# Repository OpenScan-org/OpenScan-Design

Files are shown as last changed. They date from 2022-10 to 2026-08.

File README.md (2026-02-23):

# OpenScan - 3D Scanner Designs

Here you can find, discuss and improve the existing 3d scanner designs (and current developments). The inital version was created in SketchUp and we plan on re-creating the OpenScanners in proper CAD software. If you are able to "translate" the designs into some other, more accessible format, you can also share it here.

The documentation is separated in parts, and can be found in the /docs/ folder:

[**Printing Guide**](/docs/OpenScanV2-Part-Printing.md)

[**Assembly Guide for Mini and Midi**](/docs/OpenScanV2-Assembly.md)

[**Electronics Guide for green and black shield**](/docs/OpenScanV2-Electronics.md)

[**Black Shield Manual**](docs/Black%20Shield%20V2.pdf)

# OpenScan Mini V1
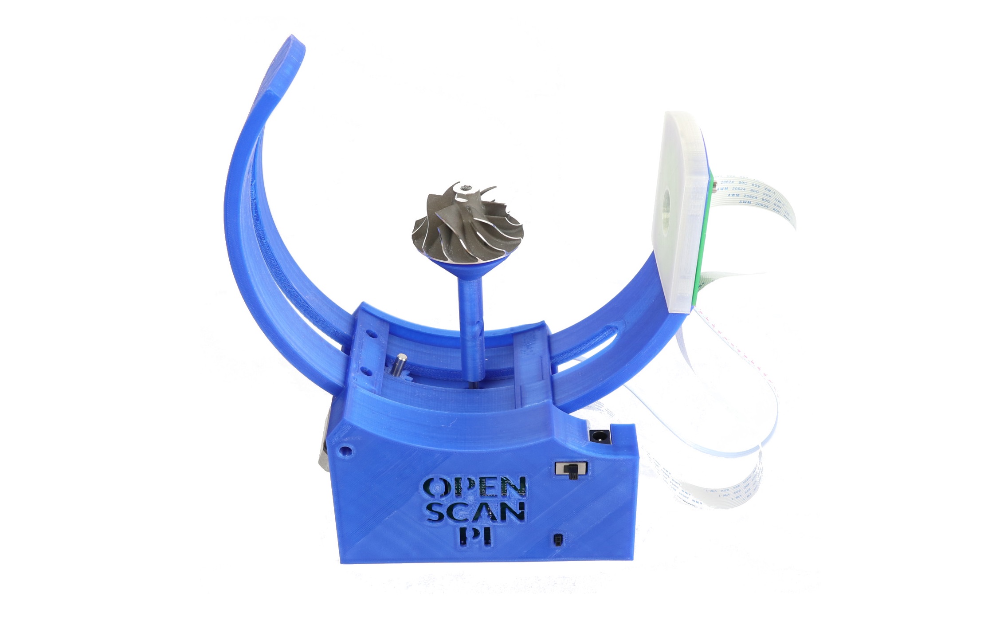
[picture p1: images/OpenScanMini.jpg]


The OpenScan Mini is the smallest version of the scanner. It has an approx. scan volume of a sphere with a diameter of 8-9cm, perfect for small and detailed parts. It features built-in LED lighting and polarizers to uniformly illuminate parts and to suppress reflections.
Version 1 is the current release with configured OpenScan software, which is described in the documentation. All hardware kits sold with the current kits are for the Mini V1 and the Classic

# OpenScan Mini V2.X
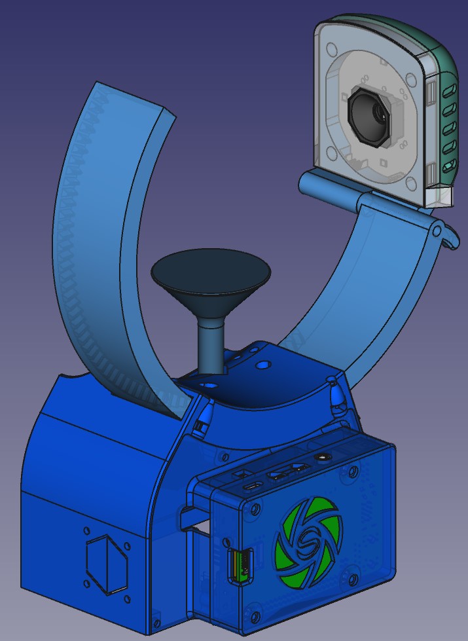
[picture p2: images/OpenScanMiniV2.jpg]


Version 2 is also available. We have seen various user mods to add functionality to the OpenScan platform. We aim to incorporate as many user mods as possible in the new design and to make adding mods more user-friendly. The idea is to increase printability, stability, and stiffness, include mounting options for user mods, and allow modular use of various cameras and lighting.
The design of version 2 is aimed at the OpenScan Shield Version 2 ("black shield", not released yet, for info, visit the Discord channel) but can also be used for the current "green shield". The BOM is slightly different from V1, various screws can be recycled, and the remaining is not exotic.

## BOM V2.0

[**BOM V2.0**](/docs/BOM-V2.0.md)

## BOM V2.1 + V2.2

[**BOM V2.1**](/docs/BOM-V2.1.md)

## BOM V2.3

[**BOM V2.3**](/docs/BOM-V2.3.md)

## BOM V2.4

[**BOM V2.4**](/docs/BOM-V2.4.md)

# OpenScan Midi V2.X
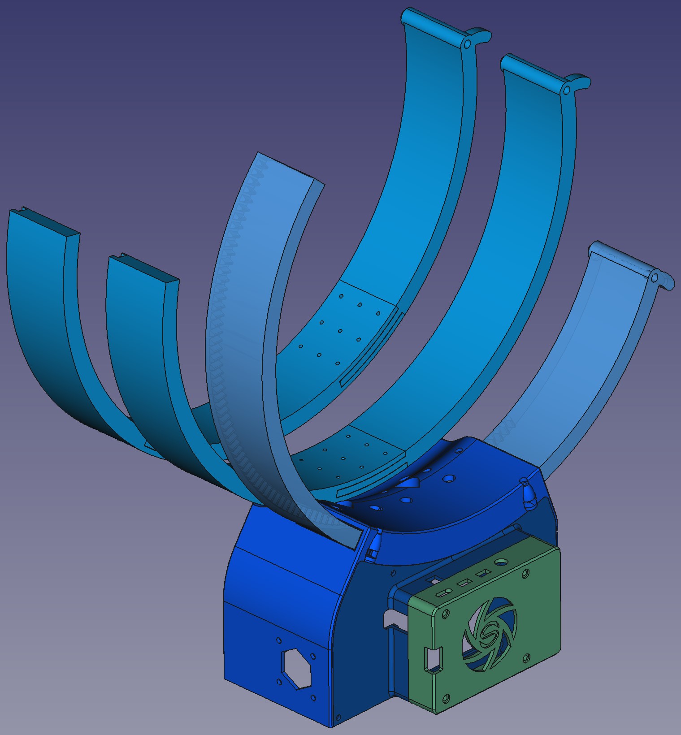
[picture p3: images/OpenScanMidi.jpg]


A scaled-up version of the Mini allows for larger objects to be scanned. The scanning volume is approx. a sphere with a 16cm diameter. This is the largest size before the flat cable for the camera slowly loses signal integrity, resulting in occasional camera hiccups. The Midi uses the same BOM as the Mini V2.
The rotor has a diameter of 30cm and is too large for many build plates. Thus, a segmented version is also provided. The segments slide into each other and are fixated afterwards with filament pieces through the 9 holes (and a little CA glue if necessary) or via M2/M2.5 grub screws of approx length 10mm. The transition of the segments must not have imperfections which could otherwise get caught in the cog wheel or brearing flanges. The large rotor benefits from the non-essential bearing upgrades to reduce wobble.

## BOM V2.0

[**BOM V2.0**](/docs/BOM-V2.0.md)

## BOM V2.1 and V2.2

[**BOM V2.1**](/docs/BOM-V2.1.md)

## BOM V2.3

[**BOM V2.3**](/docs/BOM-V2.3.md)

## BOM V2.4

[**BOM V2.4**](/docs/BOM-V2.4.md)

# OpenScan Classic
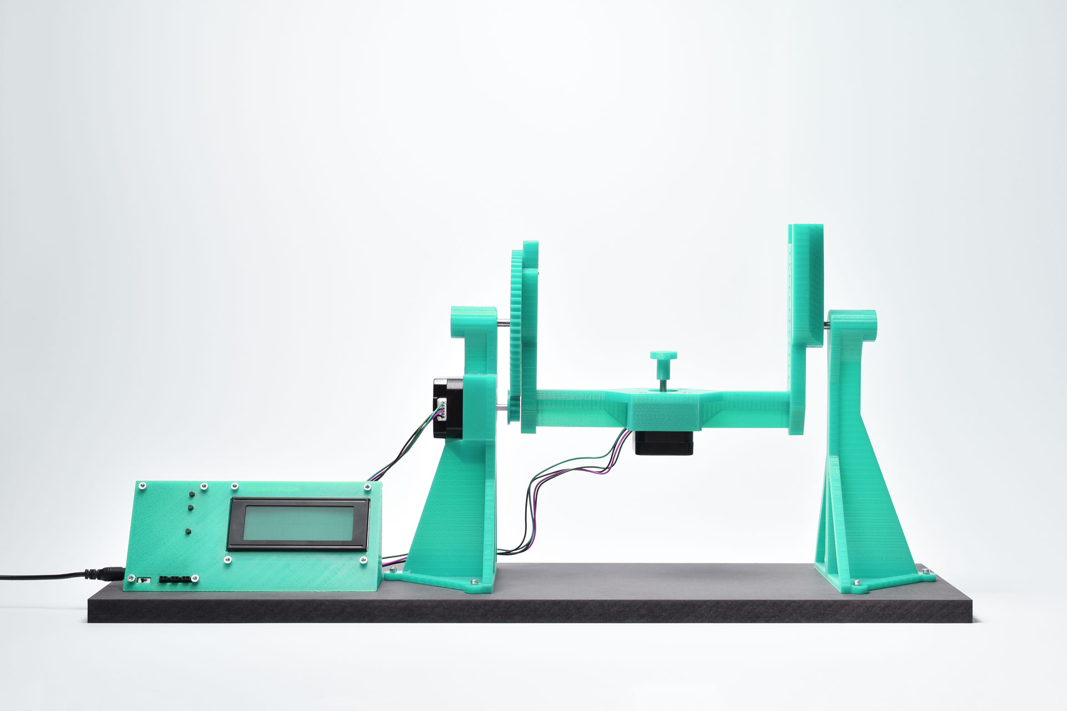
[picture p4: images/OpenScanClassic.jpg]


The OpenScan Classic is for larger objects and potential usage of external cameras. The Classic is scaled to fit much larger items. It functions the same as the Mini, except the camera is in a fixed position and the object is rotated and tilted. 

# User Mods for OpenScan Scanners
You can actively help design the OpenScan Scanners and provide user mods for others. We have seen many design tweaks and changes from users on Thingiverse and other platforms. Unfortunately, the user mods on other platforms are slowly getting lost or outdated. Here, we want to provide a platform for you to exchange your user mods and the option to curate mods so they are not getting lost in time and space. 

## Design "rules"
We recommend sticking to common design rules of 3D printing. When designing a part, printability should always be in the back of your mind, i.e., try to avoid angles larger than 45° and, if not preventable, try to include support structures already in the model so that other users will have an easier time printing. The designed part should also be rotated such that it is ready to print. For hardware parts, try to stick for parts that are commonly used in 3D printing, e.g., metric screws like M3x8mm, heat inserts like in Voron and other printers, or bearings like from skateboards or Bontech idlers.

## How to contribute Designs and provide Mods
If you are familiar with Git Hub, you already know how to contribute to projects. In case you are new to GitHub, the way would be to create an account, create your fork of the project (fork = personal copy you can edit), and then you can add (and/or change) user mods (user mods have a dedicated folder). Finally, you can create a pull request of your changes and user mods to the official OpenScan Project. After checking and approving your report and pull request, your user mods will be listed on the official GitHub page. If you are unsure about the whole process or want to share a single STL with the community, you can also ask for help on our Discord channel. The curators of the GitHub project can help you there.

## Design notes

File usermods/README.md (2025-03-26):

# Collection of your user mods.

This side is meant for adding small descriptions of various user mods. Every user mod will be placed into a separate folder.

## Small Overview of User Mods

Update the following table with the information about your mod:
- Your name
- A link to your sub-folder
- A short description of your mod
- The component the mod is designed for. Use `:heavy_check_mark:` for :heavy_check_mark:,`:x:` for :x:

like so:
`
| Creator | [Mod title](link) | Description | Mini V1 | Mini V2 | Midi | Classic | STEP | F360 | FreeCAD |`

| Creator | Mod/Folder Name | Short Description | Mini V1 | Mini V2 | Midi | Classic | STEP | F360 | FreeCAD |
| :---: | :---: | :---: | :---: | :---: | :---: | :---: | :---: | :---: | :---: |
| Alan Devine | Turntables for D-shaped Shaft | Mod name is self-explanatory. D-shaped hole provides proper form-fit of the shaft and the turntable  | :heavy_check_mark: | :heavy_check_mark: | :heavy_check_mark: |  :x: | :heavy_check_mark: | :heavy_check_mark: | :x: |
| ep1cman | Platform Holder | Base Plate with 4 slots for turntable storage | :x: | :heavy_check_mark: | :x: | :x: | :heavy_check_mark: | :x: | :x: |
| advisoray | ScanDome | Add a removable dome to block out any distracting noise from scanner background | :heavy_check_mark: | :x: | :x: | :x: | :heavy_check_mark: | :x: | :x: |
| elvum | Enhanced Diffuser (Classic) | A diffuser for the Openscan Classic with a camera shade to block scattered light, and polariser holders | :x: | :x: | :x: | :heavy_check_mark: | :heavy_check_mark: | :heavy_check_mark: | :x: |

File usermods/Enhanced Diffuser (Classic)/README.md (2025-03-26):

# Enhanced Diffuser (Classic)

This is an enhanced version of the diffuser for the OpenScan Classic.  The design has three main improvements:
* The rectangular cut-out is sized correctly for the Arducam IMX519 16MP camera that at the time of writing was the default choice for the OpenScan Classic.
* A camera shade is provided to prevent light reflecting from the diffuser entering the camera from oblique angles, resulting in wash-out.
* Holders are provided for the polarising filters to secure them in place.

In addition, templates are provided to help cut the polarising filter material to the right sizes.

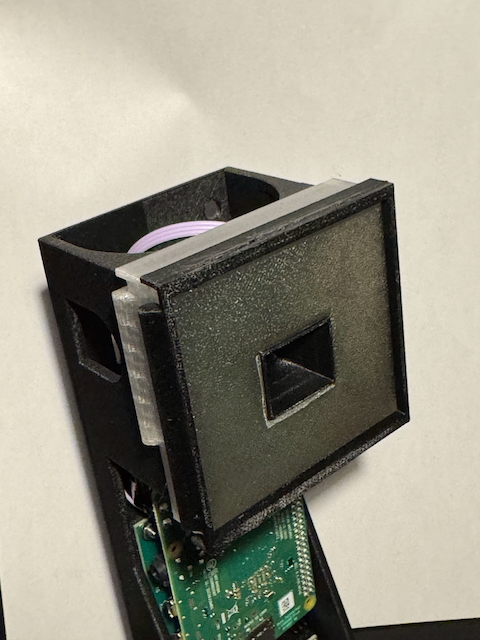
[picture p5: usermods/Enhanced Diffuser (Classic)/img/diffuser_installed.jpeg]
|  |
|:--:|
| The whole assembly, shown installed. |

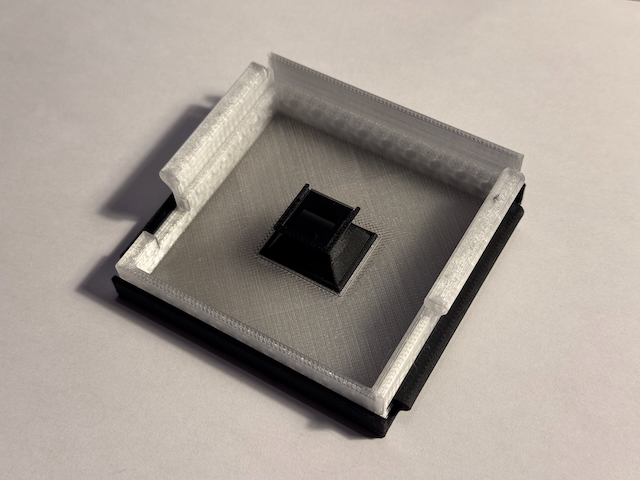
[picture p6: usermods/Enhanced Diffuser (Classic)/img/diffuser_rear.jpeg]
|  |
|:--:|
| The rear of the assembly, showing the camera shade with one of the two polarising sheets installed at its rear. |

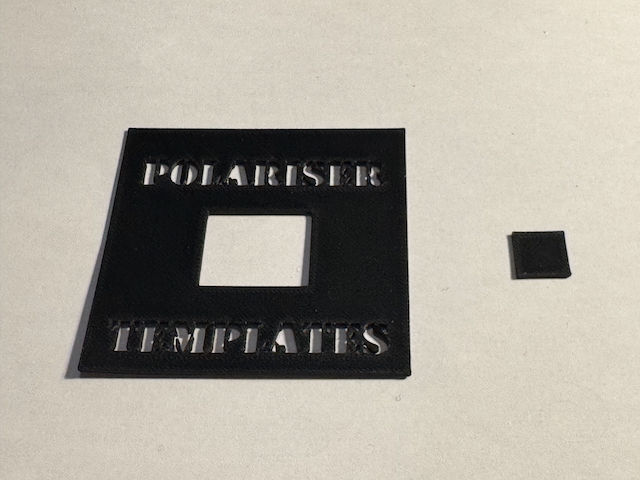
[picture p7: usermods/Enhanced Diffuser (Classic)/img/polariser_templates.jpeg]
|  |
|:--:|
| The two templates for cutting down polarising film to the correct dimensions. |

## Printing

The diffuser should be printed in an uncoloured translucent filament such as PETG.  The camera shade should be printed in a matte black material - it was tested with Bambu PETG-CF.  Other parts can be printed in whatever material takes your fancy, although they have only been tested in the same black PETG-CF that was used for the camera shade.  A textured build plate produces a nice rough texture on the face of the diffuser and is fine for all other parts too.  No support is required.

The design has been tested using Bambu Studio to slice before printing on a Bambu X1C with an 0.4mm nozzle and the Textured PEI build plate.  The 3MF file used to print it is included in this folder, along with a STEP file, STLs for each part plus the assembly as a whole, and the Fusion 360 source.

## Assembly

Unlike the original diffuser, which could be slid onto the camera enclosure from the top, this version clips onto the front of the enclosure, but uses the same rails.  No modifications to the enclosure are required.

To assemble the diffuser, insert the camera shade through the rectangular hole in the front and clip it into place - if you intend to use polarisers, make sure that the slot at the back of the camera shade is pointing upwards.  To install the polarisers, first cut out the correct profiles from a sheet of polarising plastic - printable templates are provided to help with this.  Make sure you cut out the rectangular hole in the larger sheet so that it fits around the outside of the camera shade, and make sure that the two filters are cut from one sheet of polarising material, without any rotation of the material between them.

Place the large sheet of polariser on the _front_ of the diffuser and use the large retaining clip to secure it in place.  Then place the small sheet into the slot at the back of the camera shade.

The small polariser is square, allowing it to be inserted into its holder in more than one orientation.  Make sure that it is oriented correctly by clipping the diffuser onto the OpenScan enclosure and placing a reflective plastic object in front of the camera - the lid of an aerosol can, maybe.  Launch the OpenScan web app on your computer (by browsing to http://openscan or http://openscan.local) and click "scan" to preview the live images from the camera.  Rotate the small polariser by one quarter turn and see which of the two orientations minimises the reflections as seen in the live preview.  When you have identified the right orientation, you can secure the small polariser with a dab of glue, if you wish.

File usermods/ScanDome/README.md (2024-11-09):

# ScanDome v1.2

Block out a noisy background for cleaner scans.  This is specifically built for the OpenScan Mini (Classic) v1.

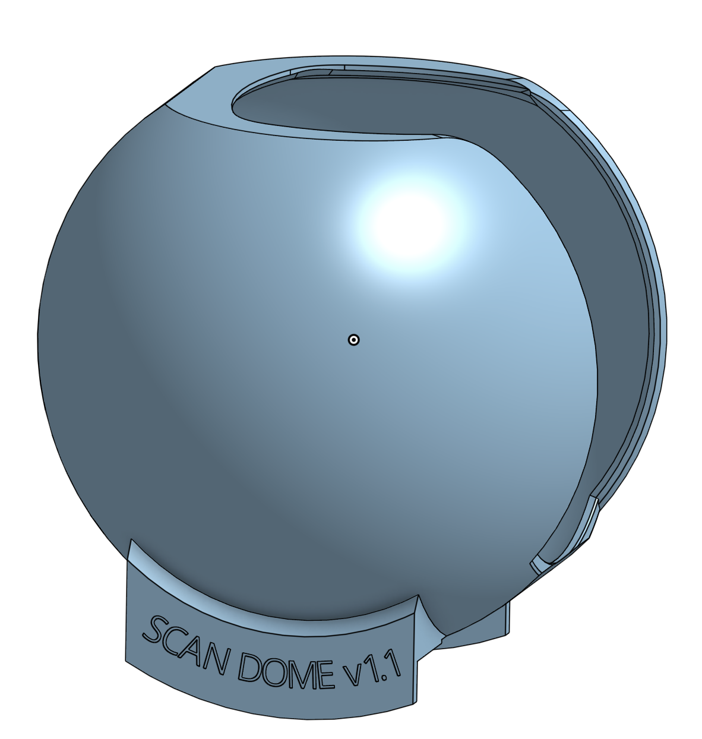
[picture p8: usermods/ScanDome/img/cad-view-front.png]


## Design

The ScanDome sits freely on the base of the OSMini (Classic) v1. The rotor will freely rotate around the ScanDome. The camera and ring light will fit comfortably through the opening.  No modification to the OSMini (Classic) v1 is necessary and the ScanDome may be removed and replaced freely.



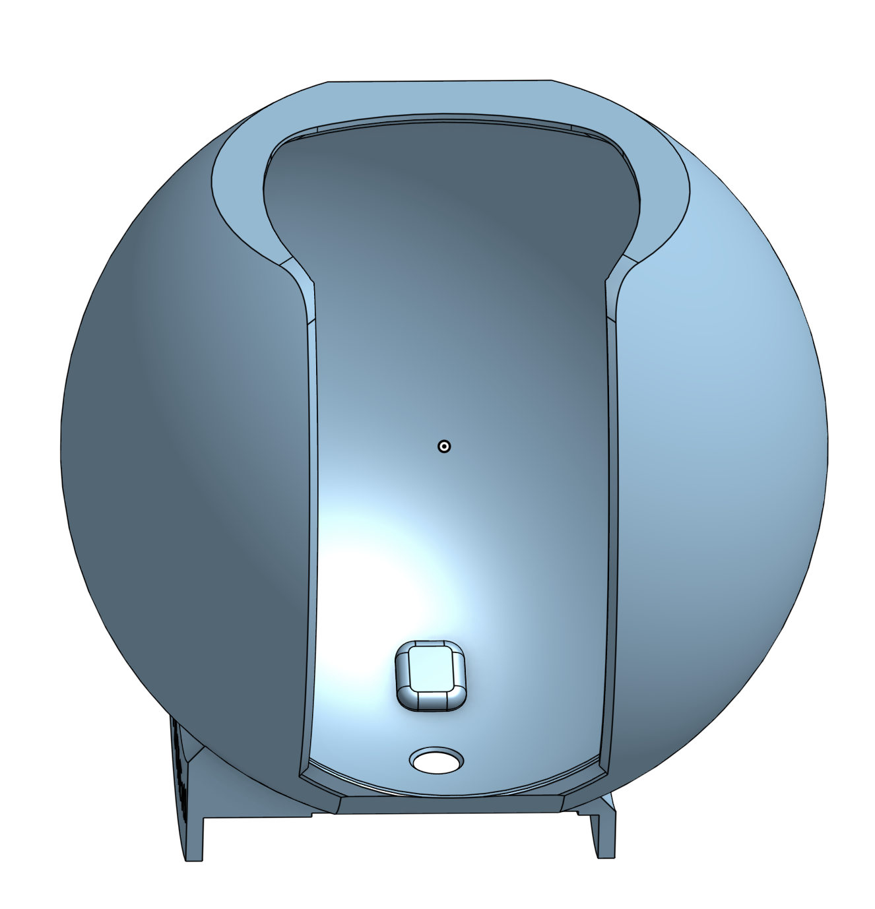
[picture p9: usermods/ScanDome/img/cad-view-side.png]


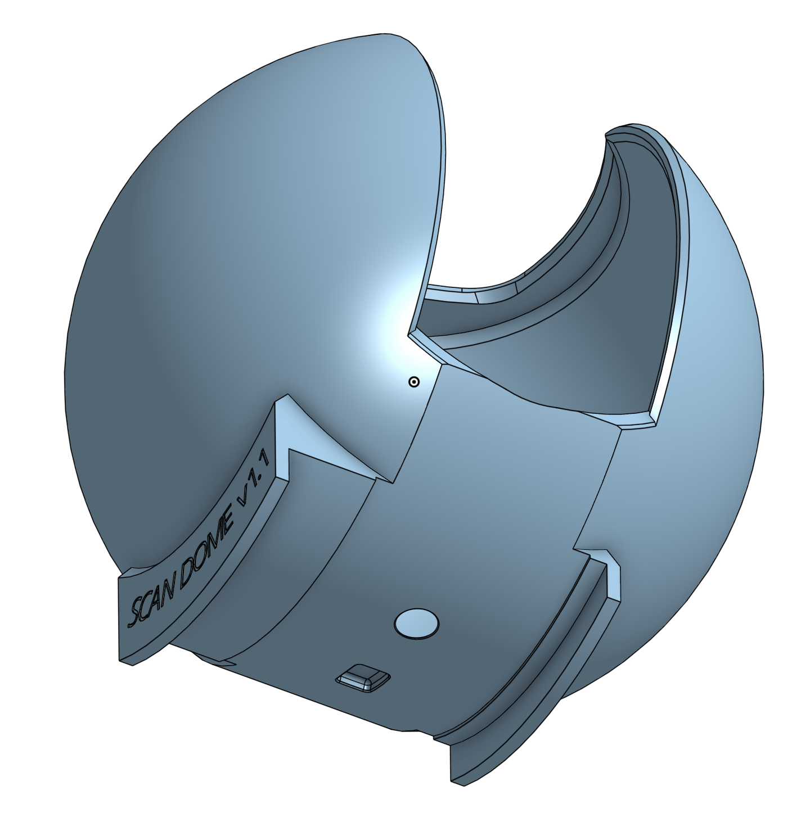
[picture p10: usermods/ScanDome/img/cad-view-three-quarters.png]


## Printing

Print on the flat surface on the top of the ScanDome (i.e., upside down from the intended deployment position).  The v1.2 version is positioned correctly so you can just import to your slicer directly and it will be correctly oriented.

Support is not strictly necessary but will improve the print quality around the hole for the turntable servo.  Low infill and low number of walls recommended -- this is not a structural part.

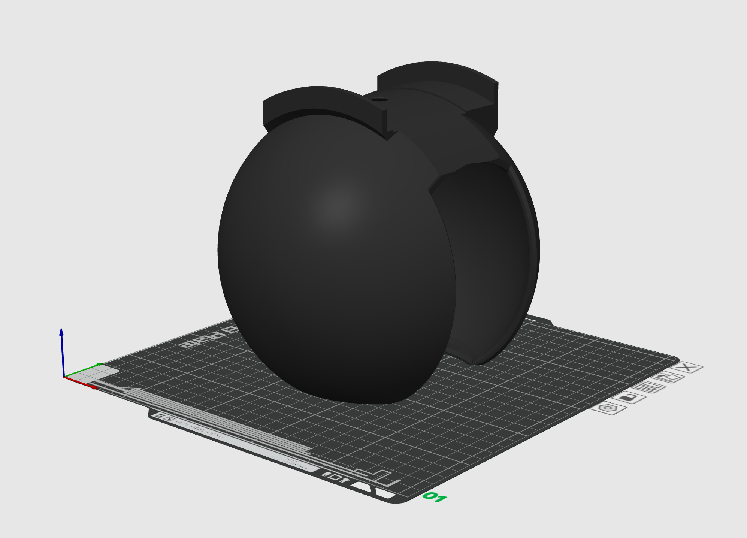
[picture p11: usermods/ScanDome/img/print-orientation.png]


## Real Example

v1.1 Printed in Inland White PLA+.

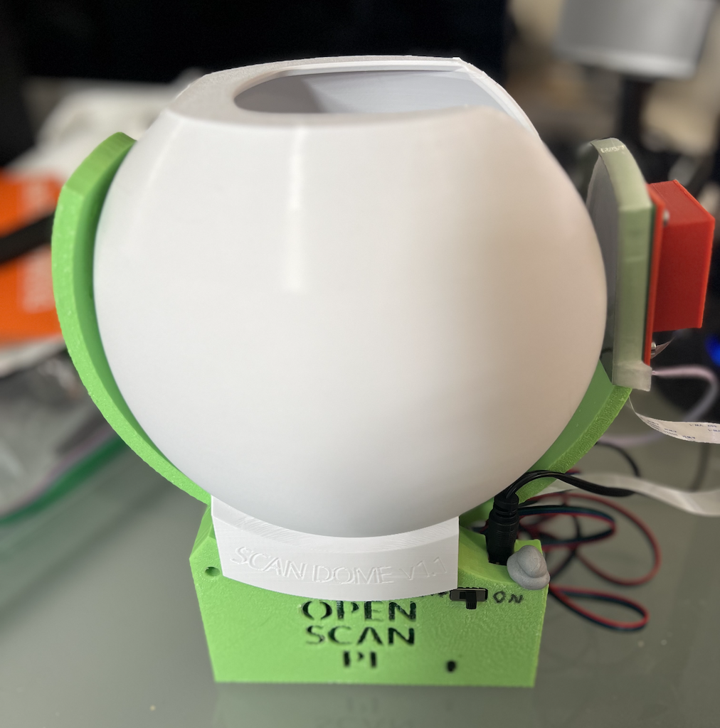
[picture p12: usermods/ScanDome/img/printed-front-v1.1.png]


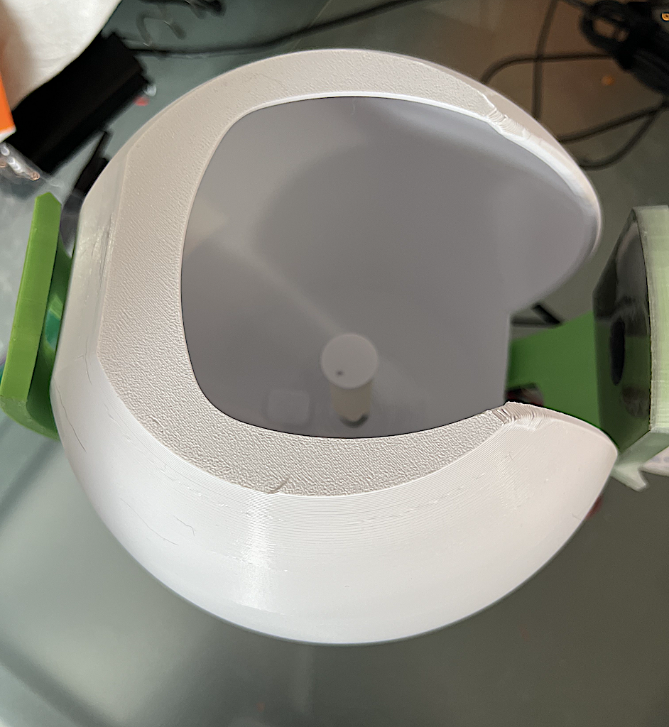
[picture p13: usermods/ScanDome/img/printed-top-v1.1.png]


v1.2 Printed in Polyterra Polylite Black ABS (No Supports).

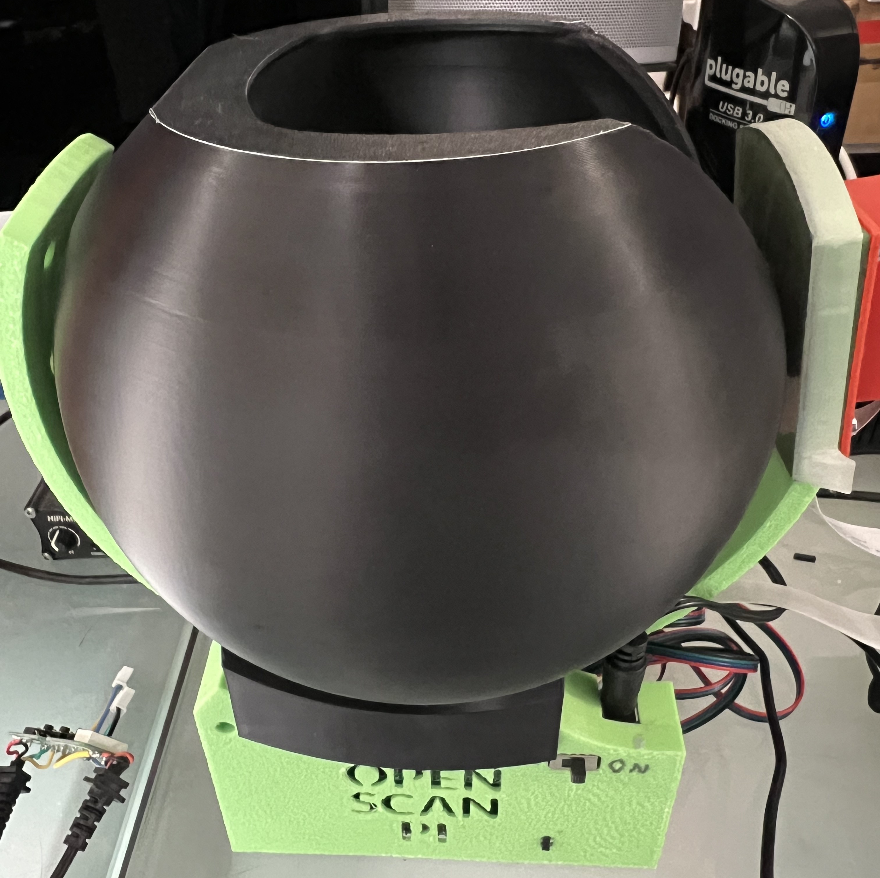
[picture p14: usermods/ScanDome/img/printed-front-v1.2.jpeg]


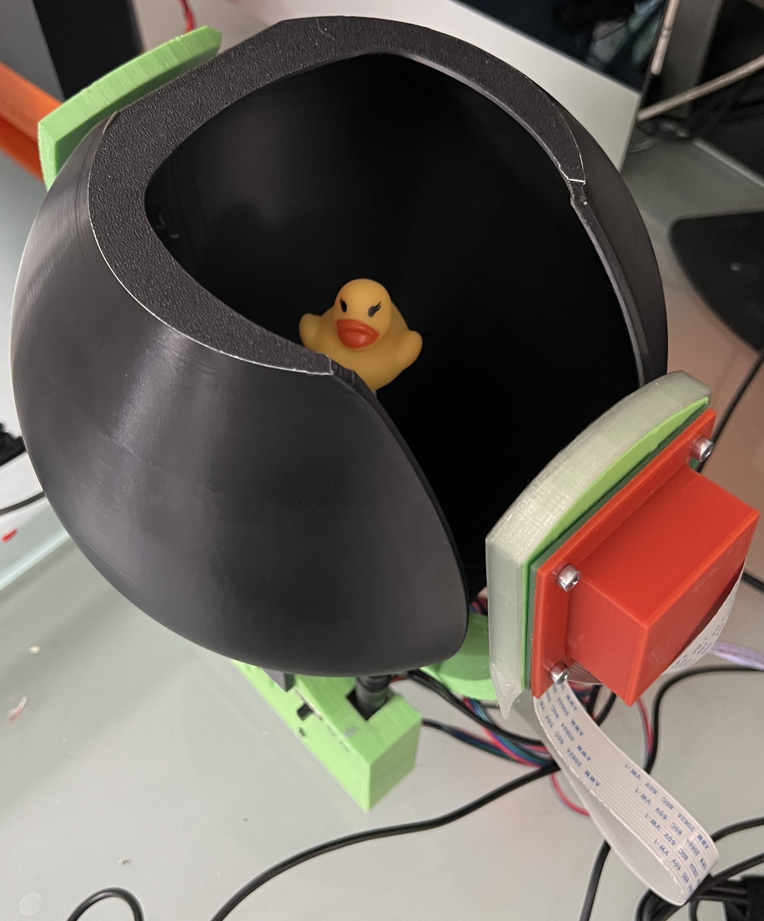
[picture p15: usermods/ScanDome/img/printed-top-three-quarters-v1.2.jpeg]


## Extending

This was designed in OnShape.  Feel free to make a copy yourself and change it to suit your needs.

v1.1: [https://cad.onshape.com/documents/bbc5671350f2efceec423882/w/e5e7f9a0af473f2fc05592b5/e/c94886a7ce4cdc3cb071335e](https://cad.onshape.com/documents/bbc5671350f2efceec423882/w/e5e7f9a0af473f2fc05592b5/e/c94886a7ce4cdc3cb071335e)

v1.2: [https://cad.onshape.com/documents/bbc5671350f2efceec423882/w/e5e7f9a0af473f2fc05592b5/e/39974ac23446baa6102c6c2a](hhttps://cad.onshape.com/documents/bbc5671350f2efceec423882/w/e5e7f9a0af473f2fc05592b5/e/39974ac23446baa6102c6c2a)

## Change Log

### Version 1.2
* Removed engraved text and version number
* reoriented print direction
* opened up hole for second servo shaft

### Version 1.1
* Initial public release

## Author

Ben Gemperline (@advisoray).  Donated to the OpenScan project.

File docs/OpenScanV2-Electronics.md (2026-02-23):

# Intro: OpenScan Electronics Start-up Guide
The OpenScan PCBs are meant for tinkerers and people with a little electronics knowledge. They are not a 100% fail-safe product (no electronics really are). In case you are not confident in dealing with electronics, here is a small, step-by-step manual on how to get the PCBs tested and running, or how to figure out where an issue is, so that you or others can help you out. This guide is written for the "black shield", but will also work for the V1, "green shield", albeit all images and references are made for the black shield. 

## Chapter 0: "Trust is good, control is better" or "Trust, but verify"
Before fully assembling your OpenScan device, you should do a pre-flight electronics check as far as you have the equipment, i.e. a multimeter, a non-conducting underground, and perhaps a Philips/Pozidrive screwdriver. You don't need any printed parts for that. *In fact, the whole process is easiest when not fully assembled, the PCBs naked in front of you on an ESD mat.* We now go through all components that can cause issues, when not handled properly.

## Chapter 1: Disconnect all components; Checking the DCDC
Remove all components, RPi, motor drivers, and cables, from the shield. You are left with the bare shield that contains only the DCDC and a few passive components. Connect a 12V power cable and switch on the shield or USB-C PD to the black shield. Nothing should happen since nothing is connected, but the DCDC will be active! With a multimeter check if you can verify GND, 12V, and 5V or more precisely 5.2V with the black shield. The black shield has status LEDs that indicate the voltage levels, so no multimeter is needed. The easiest access points are the three huge solder pads of the DCDC. If that is the case, your DCDC works, no need to check any currents since there is nothing connected that requires power, except for tiny LEDs. 
*Green Shield only:* If your 5V is off, you can adjust the voltage with the potentiometer with a screwdriver (annoying to adjust, OR flip over the DCDC, cut the potentiometer trace, and bridge the "5V" solder jumper. *I highly recommend the solder jumper bridge. It is the most reliable 5V source.*
After confirming that the DCDC works, you can continue and install jumper

Scanner

## Chapter 2: Checking the motor drivers
Switch off the shield again. Now, plug in the motor driver bricks *with the correct orientation*! The Black shield has a print written "Top" and the delivered TMC2208 also has this print. They should align. No need to connect the Nema17 motors yet. 
*Green Shield only:* Check that the heat sinks are not bridging components and potentially induce a short circuit (otherwise re-align the heatsinks and fixate them with CA glue).
Switch the shield back on. If it smells funny and perhaps you see smoke, you oriented the motor driver wrongly; the driver is now dead. Otherwise, verify the voltage, V_ref, of the motor drivers. The voltage is measured between GND and the metal case of the potentiometer. Out of the box, it should be approx 0.5V (black shield) or 1V (green shield). With a screwdriver, you can adjust the V_ref, and with that the strength (and heat dissipation!) of the motors. The Mini and Midi only require very low V_ref as there are only small forces needed to turn the rotor and turntable. 0.5V is sufficient. If you measure V_refs beyond 2V, there is a good chance you measured the voltage wrongly, or the driver burned through.

## Chapter 3: Checking the RPi
It is time to plug in the RPi (after you power down the shield again!). After powering on, the RPi should boot. This usually takes some time. You should be able to access openscan.local eventually if(!) you have correctly set up the wpa config file for Wifi before booting. If not, then I recommend an ethernet cable for the time being and set up Wifi later. Since not much is connected, not much can be done in the software at that point, but that is fine. We can confirm that the shield can power the RPi and the motor drivers. We will need a functioning RPi for the next chapters. *For that, we have to set up the config so that the RPi communicates with the correct pins.* Go to Settings -> Advanced Settings. The config of the green shield is the default and nothing must be changed. However, if you are using the black shield, then configure everything according to the following config:

Pin Config

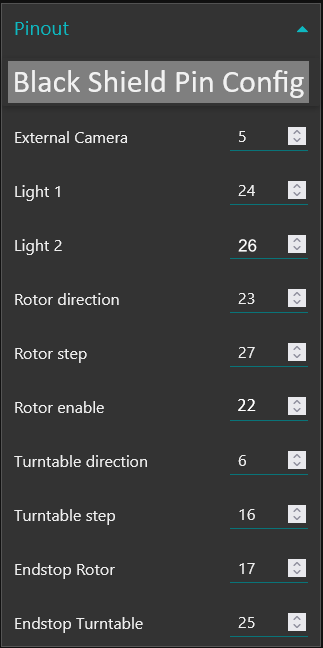
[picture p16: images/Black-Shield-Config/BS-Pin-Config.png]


Motor Config with activated endstop (see later chapter)

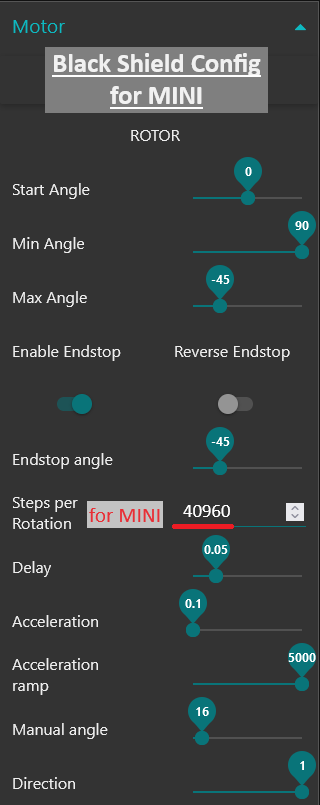
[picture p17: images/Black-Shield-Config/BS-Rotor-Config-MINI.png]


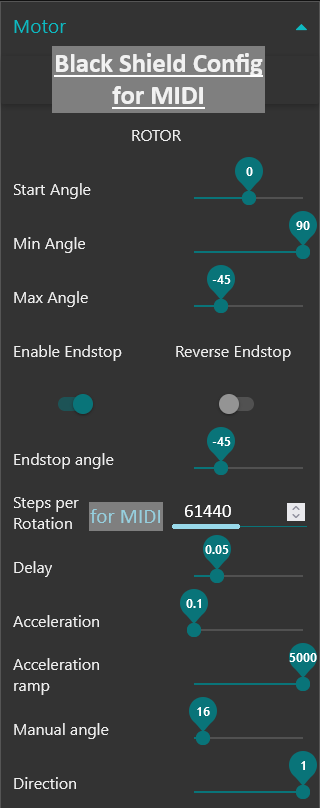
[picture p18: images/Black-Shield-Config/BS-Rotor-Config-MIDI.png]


## Chapter 4: Checking the Ring Light; Correct orientation of the connector
The ring light and shield have a 3-pin "JST-XH" terminal. This terminal prevents accidental flipping of cable connectors, i.e. pins 123 accidentally become 321. However, there are paired-end and twisted-end JST-XH cables! Due to this degree of freedom, it is better to check the pin order of the cable and not trust that any JST-XH cable will work out of the box (50% chance of getting the wrong one!). Luckily, even if you have a "wrong" one, this will not damage the ring light; the LEDs will just not have enough voltage to turn on and the ring light will stay dark.

## Chapter 5: Checking the Motor wiring
Motors come with 4 (sometimes more) connections. They are built up out of two coils, i.e. two wire pairs: one pair is labeled "1", more specific (A1, B1), and another pair with "2", more specific (A2, B2). Please read the pairing again, the  nomenclature for coil pairs is different than some people would intuitively guess! If(!) you have the tech. datasheet of your motor, you can look up the wiring. You might come across a different, more intuitive naming scheme of the wire pairs, namely (A+, A-) and (B+, B-), indicating with "A" and "B" which wires build a pair, and "+" and "-" to indicate the initial current direction that would cause a clockwise movement. If you do not have a datasheet, then you have to figure out which of the four colored cables are building pairs. There are no serious standards for wire color and coil pairing. You are on your own to figure that out.

*In any case, you start by plugging in the connector in the shield and hope the motors run immediately when commanded to move.* Go to the "Scan" interface of your running OpenScan device. You will have four arrows for manually moving the turntable and rotor motor clockwise and anti-clockwise. You simply check what the motors are doing when you click to move the turntable left/right and rotor up/down. A few cases can happen for the turntable and rotor independently.

### Case 1, everything works as intended (45% chance)
The rotor and turntable move in the right directions relative to the arrow pressed. When you press "LEFT", the turntable moves clockwise, and vice versa. When you press "UP", the rotor motor moves counter-clockwise, and vice versa. Great, you are done, your wires are connected the way the software thinks they are connected. 

### Case 2, everything works, but the direction is reversed (45% chance)
The motor moves in the opposite direction, as described in case 1. That can easily be fixed. Instead of physically switching wires of the connector, you can invert the direction  in the software settings, under advanced settings. There is an ON/OFF toggle for the motor and turntable direction, that inverts the the movement direction. After changing settings, your motors should now move in the direction they are supposed to move.

### Case 3 (10% chance)
When clicking the arrow buttons, a motor vibrates very quickly back and forth and makes a buzzing, humming, or squeaking sound. One of the pairs is unfortunately twisted. You have to untwist them:
 
*Cavemen method:* randomly pick two wires, e.g. (1,2), take a small screwdriver, carefully remove the metal pins from the connector, and re-plug them in switched order. Re-do the testing. If you now have case 1 or 2, you randomly selected two right wires, congratulations. If not, then now pick one of the previously picked wires and a previously not picked one, e.g. (1,3) or (2,4), and repeat the process. Despite being the least scientific method, this is typically the quickest.

*Scientific method:* The connector on the black board has the orientation (A1,B1),(A2,B2)). Which *direction* the coils are and which coil is "1" and "2" is currently unknown. You measure the resistance with a multimeter across pairs of wires. A pair has a very low resistance, a few Ohms; it is only a coiled-up wire after all. That is how you find the pairs. 
This leaves you guessing "A" and "B", the direction of the coils. Luckily, if you guess wrong twice for both coils, the error cancels out, and you simply invert the moving direction, which the software can fix. If you guessed right and false once, then you get the buzzing/humming/squeaking sound. Then you have to twist *one* coil pair. The motor should now move without buzzing.

## Chapter 6, Installing an endstop for the rotor
The OpenScan device does not know the rotor position when freshly booted, thus also no knowledge of how far up and down it can move the rotor before an accident happens, either the rotor disengaging from the gear or bumping into the base. Without an endstop, it is the user's responsibility to manually move the rotor to its starting position before every scan. This potential error source can be eliminated when installing an endstop to the V2 Mini and Midi. The endstop is triggered shortly before the rotor hits the base, thereby immediately end all movement, hence its name. This position can then be used as a starting point for a trustworthy coordinate system for the OpenScan device. The endstop implementation follows the industry quasi-standard of fail-safe endstop implementation:

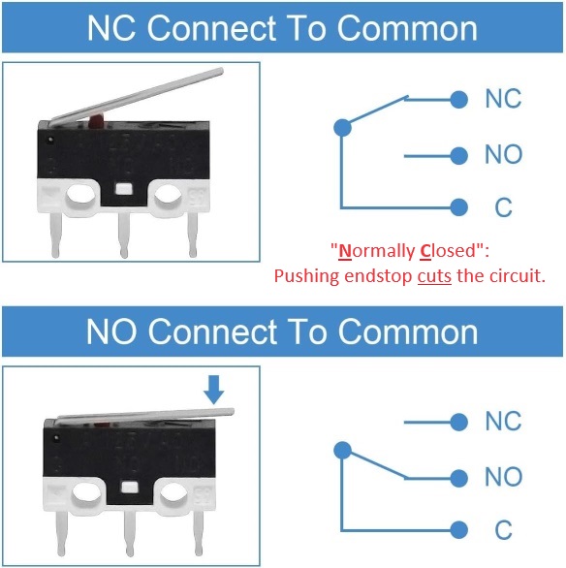
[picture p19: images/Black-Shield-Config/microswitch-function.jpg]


(1) The endstop is used as "normally closed" = NC, i.e. the right terminals for NC must be used. "Normally Closed" means, the endstop closes the circuit between the "Common" or "Com" or "C" terminal and the "NC" terminal when the button is NOT pressed. Vice versa, this circuit is cut, when the button is pressed.
(2) The GPIO is connected to the NC terminal of the endstop. The COM terminal is connected to GND. Thus, The circuit is normally closed to GND.
(3) This GPIO will be configured to internal pull-up, i.e. the GPIO will be HIGH (3.3V) when nothing pulls down its voltage level. Many microcontrollers have GPIO with configurable internal pull-up configuration, if not, then a hardware pull-up with a 100k resistor between the GPIO and 3.3V level is fine, too.
(4) Since the circuit is normally closed, the circuit to GND wins the "battle" against the pull-up. This means the GPIO senses LOW.
(5) When sensed HIGH on the GPIO (caused by the pull-up), the endstop routine will be triggered.

Fail-safe explained: Whenever the endstop is pressed *OR* the circuit fails/breaks for whatever reason, the GPIO will set itself with the help of the built-in pull-up to HIGH. This triggers the endstop routine. This is often coined a fail-safe implementation because the endstop routine will also be triggered when your cat/dog/hamster chews through the cables or anything else happens to the circuit.

All you have to do is to install the endstop described and the images below, and enable the endstop routine in the advanced settings.

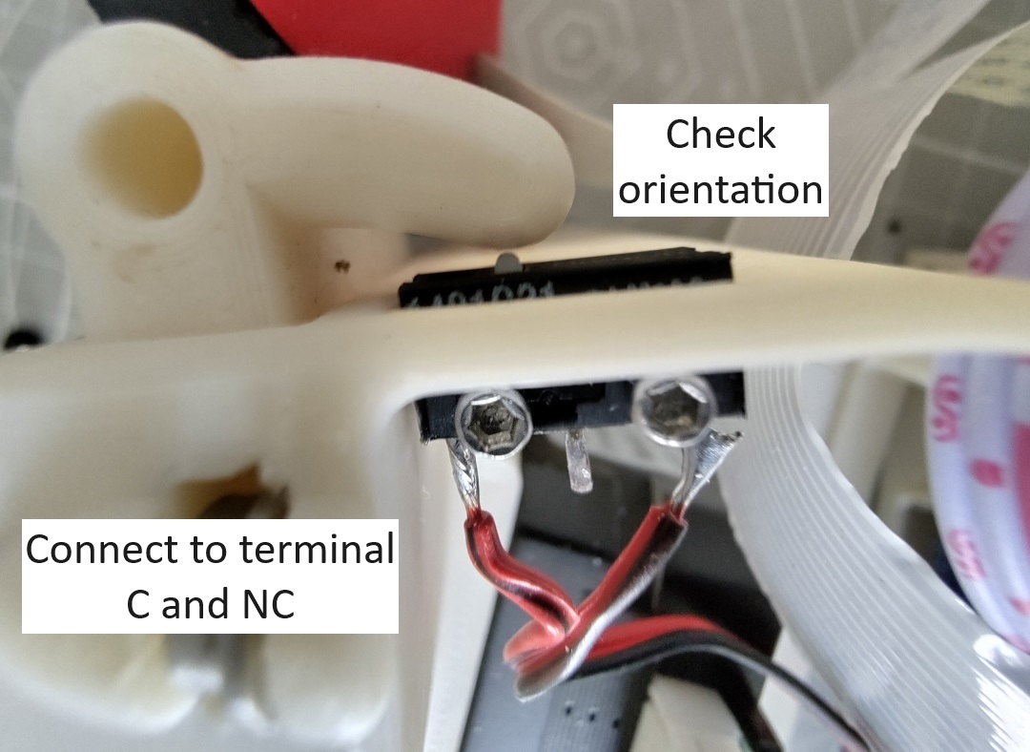
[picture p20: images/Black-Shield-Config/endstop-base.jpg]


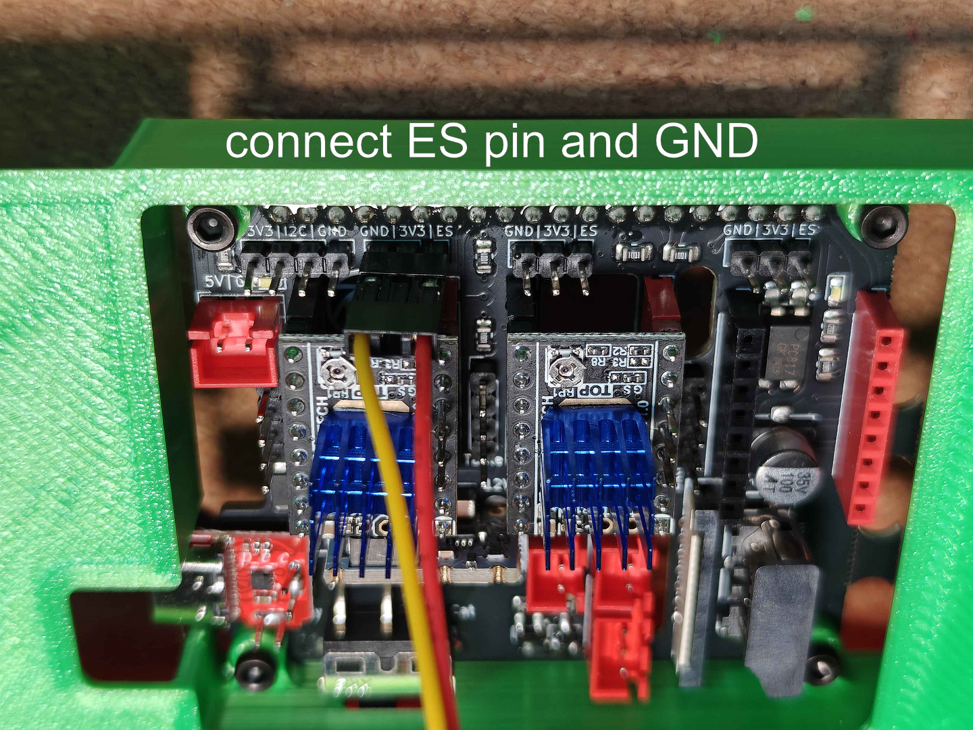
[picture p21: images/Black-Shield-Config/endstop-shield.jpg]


Whenever you start your scanning routine, the rotor will first move to the base, trigger the endstop, and then use that position as a reference for moving to the scan positions.

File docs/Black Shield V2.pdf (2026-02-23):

BLACK SHIELD V2.X FOR OPENSCAN COMMUNITY SHORT DES CRIPTION
The Black Shield is a Printed Circuit Board (PCB) for OpenScan devices. It provides convenience by simplifying the electronics part of the project. The shield unifies all electronics. It comes with power management for Raspberry Pi, driver slots, LEDs, and terminals for endstops.
REQUIREMENTS AN D GETTING S TARTED For a full OpenScan device, the following additional components are needed:
- RPi 3B+ or more powerful (Pi Zero not sufficient/recommended)
- RPi-compatible camera
- USB-C PD charger 24W+ with 12V and 2A+ rating
- Nema17 motors of your choice
- For best compatibility, an RPi 4 with 4GB and IMX519, as well as a powerful, 65W single USB-C PD charger is recommended.
The whole shield comes in one piece with multiple sections connected via “mouse bites”, which are break-away elements. Carefully bend the board close to the mouse bites without pressing on components of the board. The mouse bites should break with minimal effort. A flat plier or edge of a table helps in localizing the bend! PRE-FLIGHT CHECK – WITHOUT R PI Unfortunately, shipping companies are sometimes not careful with handling things, so the Black Shield comes with status LEDs, guiding users through a checklist to test for functionality. Please follow the pre-flight checklist for your Black Shield and PSU before fully assembling everything. Without installing the RPi, motor drivers and motors, connect the Black Shield to a PSU and switch it on:
1. Testing your USB-C PD PSU for 12V:
a. Ideal scenario: you see four bright green LEDs. The Black Shield is powered with the correct 12V. Continue with Pre-Flight Instructions.
b. Four dim green LEDs. Your PSU delivers less than 12V, probably 9V. Probable cause is your USB-CPD PSU does not support 12V and uses 9V instead.
c. Four LEDs are off, but a single Blue LED is on, then your USB-C charger is not using PD and only provides the standard 5V any USB port delivers.
2. Testing the DCDC functionality: The single blue LED is lighting up. The DCDC converter is working and running and is delivering 5V to the RPi gpio header.

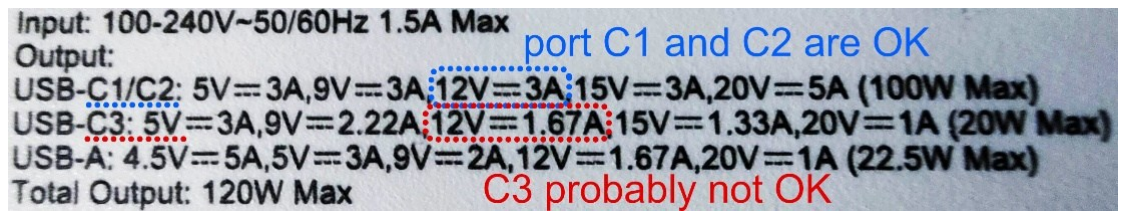
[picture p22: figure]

Compatibility of USB-C PD charger is, unfortunately, an issue with “unorthodox” chargers. Fortunately, USB-C chargers come with functionality and voltages printed on them for all ports. Search for 12V and the current rating behind to find the right port. PRE-FLIGHT CHECK – WITH RPI When your Black Shield passes the previous test, then it is ready to be installed onto the RPi. When switching on the Black Shield with RPi (SD card and motor drivers for initial test not needed), a single orange LED at the other end of the GPIO pin socket should light up, indicating that 3.3V is delivered by the RPi to the Black Shield. Your Black Shield now has all voltage levels working – 12V, 5V and 3.3V – and is ready to be used for your OpenScan Device.
MOTOR DR IVER INSTALLATION AND CONFIGURA TION

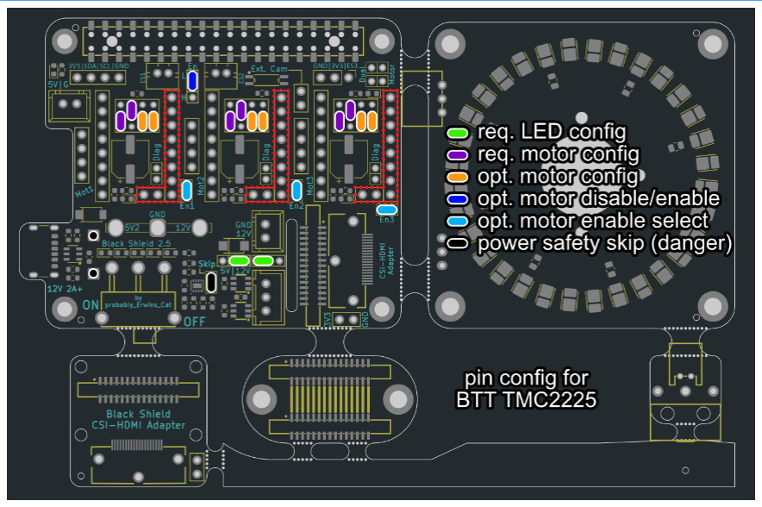
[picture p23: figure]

The motor drivers usually have color coded pin header, black and red for the TMC2225. They must be inserted with the correct orientation, see image above, red dashed line. The drivers also come with a tiny pinout, indicating the orientation.
The board needs minimal pre-flight setup. Motor drivers require configuration of “microsteps”, purple-marked jumper positions. Current OpenScan software is assuming 16 microsteps in standard configuration. The user must install jumpers for MS1 and MS2. For TMC2225, you can follow the provided configuration, as seen in the image: [Low, High, Low, Low] from left to right. This configures [MS1, MS2, MS3/UART, UART/SLP]. When using other drivers, please refer to their manual for microstepping. Some jumpers are optional and depend on the drivers used, i.e. Enable functionality and UART communication channel. I recommend installing also the optional drivers, because some firmwares/configurations require them (and also to not lose the left-over jumpers!).
LEDs also need a pre-flight setup for selecting the Voltage and functionality. The light provided needs 12V power line. The Black Shield also supports NeoPixel with 5V, however, not implemented in current firmwares.
The Vref is set to a reasonably low value per default, 0.8V, as most OpenScan devices only require low torque for moving rotors and turntables. Large custom OpenScan designs might require higher torques. If you experience skipping in your motors, you can carefully adjust the Vref and thereby the motor current and torque. Higher currents might require a stronger PSU.
PHYSICAL ENDS TOP CONF IGURA TION The Black Shield supports endstops. The rotor benefits from absolute coordinates the rotor endstop provides. For endstops (ES), there is a recommended way for configuration that the Black Shield follows:
- Endstop: wires attached to COM/Base and NC (normally closed) terminal
- RPI/circuit: Wires attached to GND and free GPIO pin (ES pin)
- ES pin configured as (internal) pull-up
This implementation triggers the endstop routine when anything breaks the circuit going from ES pin to GND or when something is wrongly configured/defect. This is a safety measure. Normally, the circuit is only broken when the microswitch is pressed, which triggers the endstop routine correctly.
The software is agnostic where the endstop is located and which the rotor moves first. In the software, the user can set the minimum and maximum angle for rotor movement, defining the coordinate system after the endstop routine is triggered. Further the motor movement direction can be set. The user must try out whether the maximum or minimum angle is the assumed position of the endstop and in which direction the rotor is moving. Unfortunately, this step involves trial and error depending on the firmware/software you are using.

MOTOR DR IVER CONFIGU RATION – UAR T (FU TURE SOFTWARE ONLY) RPi can alternatively communicate via UART with drivers for configuration. At the current state, only a development branch of Composer can use UART. However, future firmware, OpenScan3, will include modularized software and UART support. The Black Shield already includes all hardware requirements for UART.
Under UART, MS1 and MS2 will not configure microsteps, but the UART address, i.e. two drivers must not have the same address. Remove the optional jumper from position 3 and 4 to enable UART communication. Use jumpers on positions 1 and 2 to give each driver a unique address, e.g. [L,L], [L,H], [H,L] and [H,H].
If the user uses virtual endstops, i.e. sensorless homing, then the physical endstops must be unplugged from the Black Shield, since the physical and virtual endstop share the same GPIO and would interfere with each other! Add a jumper to the DIAG header. The RPi can now read out the driver, needed for sensorless homing. A small red LED will indicate when the sensorless homing routine is triggered.
GPIO CONFIG URATION
Community-driven Firmware Meanwhile or Composer are recommended for the Black Shield, as there are already pre-built configurations provided. Future software “OpenScan3” will follow. In those firmwares, you must go to Settings and select the shield version you have, i.e. Black Shield. All settings will automatically be applied. After rebooting, most devices will work without further interventions. Note, the software assumes you are using motor slot “Mot1” for the rotor, and “Mot2” for the turntable.

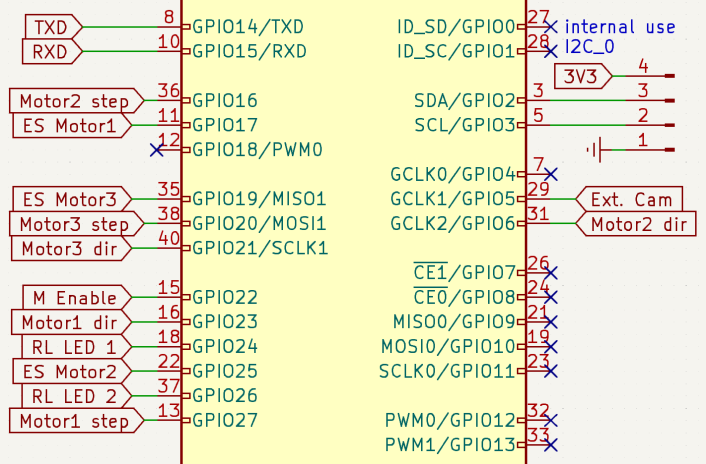
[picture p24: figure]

When using other firmware, the GPIO must be manually configured. You must enter the GPIO of the official Black Shield schematics into the (advanced) settings of the firmware of the corresponding functions, e.g. rotor direction, rotor step, LED On/Off, and so on. Please see the pinout of the schematics or documentation.
GEAR CONFIGURATION, STE PS PER FULL RE VOLU TION Every OpenScan device uses a stepper motor to rotate a shaft/gear that rotates a turntable or rotor. The software is agnostic about the de sign details of the Scanner at first, so the user must manually configure parameters like gear ratio and steps per full rotation, so that commands like “move rotor by +15°” is translated properly into the correct number of microsteps “move gear by 1707 steps”.
This configuration is already included in Meanwhile and Composer and is automatically updated when selecting the Black Shield in the configuration. In the case of updates of the CAD design or software, those parameters can vary slightly, so it is always a good idea to double check the pre-configured values with the recommended.
For custom scanners: To calculate the number of microsteps per full rotation, the user must know the number of gear teeth of the two meshing gears, resulting in the gear_ratio of (large:small gear). The microsteps per full rotation can then be calculated [e.g. for Mini]:
steps_per_rotation = 200 ⋅ microstepping[16] ⋅ gear_ratio[128/10]
MOTOR PINO UT – AABB, ABAB, ABBA Stepper motors come with 4 (rarely with 6) pins split up in 2 pins per coil. Unfortunately, the nomenclature of those pins, their coloring and pairing is not really standardized. A messed-up pin order is not the end of the world but will prevent your motors from working properly. Your motor, when connected to the shield, will most likely work out-of-the box but not guaranteed. If you are unlucky, the motor will make a buzzing sound due to wrong pinout. In case, follow this re-pinning guide:
- The shield expects a pairing of AABB for the coils A and B.
- Switch the pins 2 and 4 while the device is off. Either you transformed ABBA to AABB (yay), or ABAB to ABAB (nothing changed). Test again.
- If still buzzing, switch now pin 2 and 3. You transformed ABAB to AABB. PRIN TING THE PARTS AN D ASSEMBLY If this is your first device, just print the most recent version of V2 and skip this section. Some parts come with integrated support structures that must be removed.

While most parts are compatible between all versions of V2.X, some parts have small changes that partially interrupt inter-version compatibility. When you plan on upgrading, please check beforehand which parts must be reprinted. All printable files of all versions will stay available in the design GitHub of OpenScan.
You will find minimalistic assembly instructions in the GitHub repo. Due to incremental design changes, the provided images might not always correspond to your V2.X model but may be taken from a previous version 2.Y. Don’t worry, the parts will look very similar, and every part has a leading number in the file name, corresponding to the assembly step.
Note, the Black Shield comes with height adjustable GPIO header! By carefully pushing and wiggling, you can slowly move the header up or down in the socket. Make sure the header sits properly on your Raspberry Pi before fully assembling the electronics compartment.
CSI CABLE EXTENSION
Whenever you are building a larger scanner, you
will find typical CSI cables too short, e.g. the golden camera cables stop at 500mm length. This is sufficient for the Mini V2.X but the Midi
needs approx. 650mm length for full range of the
rotor. The Black Shields comes with dedicated

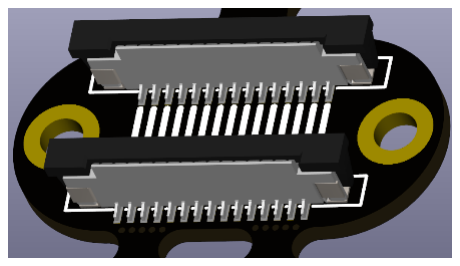
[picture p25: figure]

CSI cable extension that screws to the base. This also makes routing the long flat cables slightly easier. Use the rounded head screws and nylon lock nuts.
CSI-HDMI ADAPTER
The Black Shield comes
with an optional CSI-HDMI
adapter. Your standard
Mini or Midi does not need this adapter, but perhaps
tinkerers will enjoy it. Very long flat flexible cables of

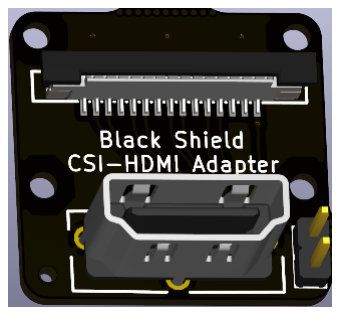
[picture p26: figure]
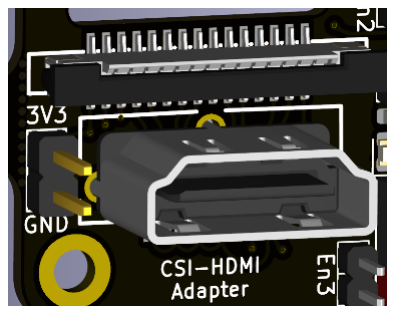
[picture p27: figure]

the camera have poor signal integrity that might be needed in custom OpenScan devices of large size. HDMI cables have superior signal integrity. Thus, when transporting camera data a long way, you want to send it via HDMI cables instead of flat flexible cables. The CSI-HDMI adapter is pairing the data lines of the camera into the differential pairs of HDMI cables. Tests confirmed that you can transport camera signals easily through 5-meter HDMI cables with IMX519. However, due to the plethora of camera models and signal pinouts, I cannot guarantee that the adapter will work for all camera models and could only test and confirm functionality with the usually used cameras.
INSTALL ING AND SETTING UP THE POLARIZERS

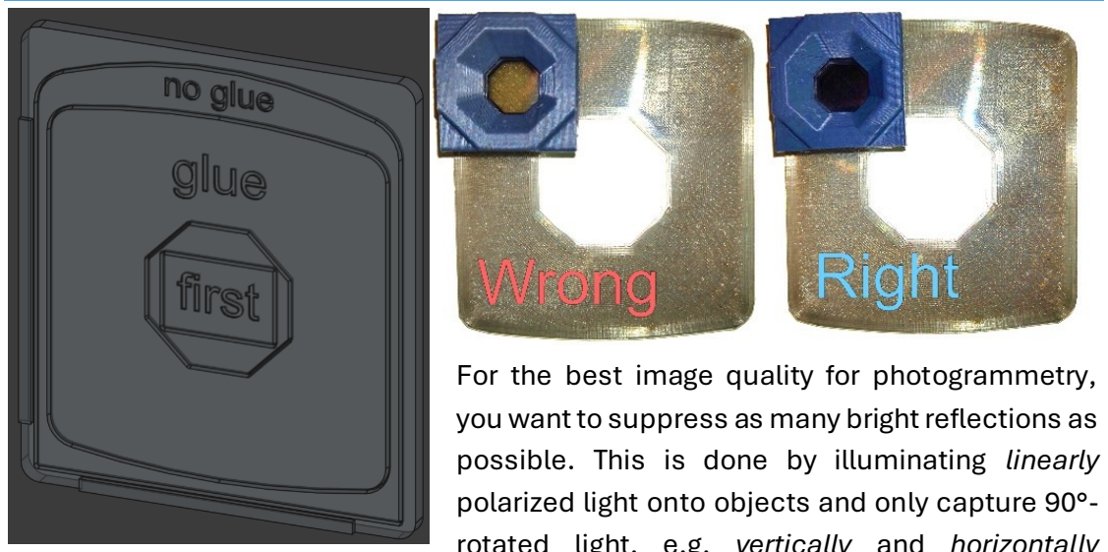
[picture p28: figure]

For the best image quality for photogrammetry, you want to suppress as many bright reflections as possible. This is done by illuminating linearly polarized light onto objects and only capture 90°-rotated light, e.g. vertically and horizontally polarized light. The light that can pass two polarizers depends on the angle between the polarization axes. An angle of 90° results in virtually no light passing, see right image. Look through both polarizers and check that no light passes. If so, then this relative orientation of both polarizers is the 90° polarization configuration.
Use the optional printable cutting guide and a sharp blade.
Polarizer for Camera: One small sheet must be inserted to the tiny slit of the camera eye piece, blueish piece above. Non-adhesive should be used here. You can use the cutting guide to cut out the rectangular center piece of sheet of polarizer foil. Afterward, cut out the hexagonal center piece for the next step.
Polarizer for Light: If you are using non-adhesive foil (contained in the kit), you must sandwich the foil between the assembled imaging unit and the polarizer hood. Alternatively, use a droplet of CA glue and glue it on the polarizer. If you are using adhesive foil, you can trim the foil to the size of the diffusor, and glue it on, see image above. The cutting guide comes with both outlines.
Don’t forget to remove the protective films and prevent fingerprints! Both can influence the polarization and reduce image quality significantly!

WARRANTY CLAIMS AN D SUPPORT Please be aware this is a DIY project, and I cannot take responsibility for damaged devices when not handling carefully. Currently, less than 3% of users reported (partially user-caused) damage and most of them were minor issues, like one of the many LEDs of the ring light being dead. I try to help with replacing parts as conveniently as possible (even in user-caused damage) if necessary. While the Black Shield is simple enough constructed that I have all the tools, can repair damages, and replacing components, this does not mean that every user has and can (or want). Thus, I offer a limited replacement service, where the user sends back a damaged shield, and I send back a new shield. Up to now, I could repair all (user-caused) damage. To keep e-waste to a minimum, repaired shields are then sold at a discount for tinkerers.
AVAILABIL ITY OF SCHEMATICS The schematics for all versions of the Black Shield are always available on discord as PDF for future references. The schematics will also be added to the updated official OpenScan documentation. For educational purposes and support for tinkerers, I added many comments of essential and optional parts. With that, anyone with basic knowledge in KiCAD or similar can develop and improve on my design. However, I reserve the right to not share the Gerber files publicly with any anonymous person to protect the project and community from copycats, i.e. aliexpress…
KO-FI SUPPOR T
The Black Shield is currently only produced in small quantities. To provide the Black Shield to more users and continue the support and integration of more features, financial support would be greatly appreciated. If you consider yourself a frequent user of photogrammetry, I would appreciate one-time or monthly donations under: https://ko-fi.com/probably_erwins_cat
This helps separating the production and sale cost of the Black Shield from the prototyping, development and inventory costs in the future as much as possible, so future Black Shields and accessories can be developed independent of sales price and potentially can be provided less expensive in the future. For questions and support, you can write to me on various platforms, GitHub, Discord and Ko-Fi: probably_erwins_cat

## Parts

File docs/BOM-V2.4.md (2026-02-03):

# BOM V2.4

Mini and Midi are using the exact same BOM for the basic hardware parts. The only difference in the required parts is the length of the needed electronics cables, i.e. ring light cable and camera cable.

## Essential BOM V2.4

| Part | Amount | Short Description |
| :--- | :---: | :---: |
| M3x8mm SHCS/BHCS | 8+3+4 | Nema17 motors, base cover, imaging unit (IU) |
| M3x40mm+ SHCS/BHCS | 1 | mounting IU to rotor, any M3 equal or longer than 40mm will work, M3x70mm would be perfect, see non-essential BOM |
| Heat Inserts M3x4x5 | 3+1+4 | sometimes called "Voron" inserts for base, rotor, and cam mount. Must be 5mm diameter! 4.6mm diameter will not sit securely. They require a soldering iron to melt them in. |
| M2.5x18mm standoff *female-female* | 4 | standoffs sandwiched between RPi and black shield |
| M2.5x10mm SHCS | 8 | fixating RPi, shield, electronics cover and base cover |
| M2x8mm SHCS | 2 | optional screws for fixating camera if friction fit is not enough |
| lubricant | 2-3 ml | lubricant that doesn't dissolve printed parts, i.e., white lithium grease, for cog wheel |

## Non-Essential BOM (Luxury and tinkerer upgrades)

### Endstop
| Part | Amount | Short Description |
| :--- | :---: | :---: |
| microswitch w or w/o lever | 1 | endstop: standard microswitch found in many 3D printers, quality ones prefered (e.g. Omron D2FC) |
| M1.6x12 or M2 self-tapping | 2 | endstop: fixating the endstop, screw directly into the plastic |

### Lighting Dome
| Part | Amount | Short Description |
| :--- | :---: | :---: |
| Heat Inserts M3x4x5 | 2 | mounting points: for lighting dome mod |
| M3x35mm SHCS/BHCS | 2 | mounting points: will replace two M3x8 from turntable, for lighting dome mod, sandwich dome mod adapter  |
| M3x12mm SHCS/BHCS | 2 | for lighting dome mod, fixating the dome and adapter to the base |

### Anti-wobble Rotor
| Part | Amount | Short Description |
| :--- | :---: | :---: |
| stripes of satin/velvet sheets | 3-5 | glue 5-10mm wide stripes of 0.5mm thickness satin along rotor, strong dampening effect, reduce rotor wobble |

### Sturdy IU mounting
| Part | Amount | Short Description |
| :--- | :---: | :---: |
| M3x70mm SHCS/BHCS | 1 | mounting IU to the rotor, put a heat insert on the *opposite* side of the rotor, extra stiffness |

### CSI Cable Extender
| Part | Amount | Short Description |
| :--- | :---: | :---: |
| CSI Cable Extender | 1 | the extender should respect the pin flip, e.g. adafruit extender or Black Shield Extender |
| M3x8mm SHCS/BHCS | 2 | fixating CSI cable extender to base |
| M3 nuts | 2 | fixating CSI cable extender to base |

### Cooling Fan
| Part | Amount | Short Description |
| :--- | :---: | :---: |
| Fan 3010 or 3007 | 1 | motors and drivers are producing heat which can soften PLA over time; 3V3, 5V, or 12V |
| M3x14 SHCS/BHCS | 4 | for mounting the fan into the housing |
| M3 nuts | 4 | for mounting the fan into the housing |

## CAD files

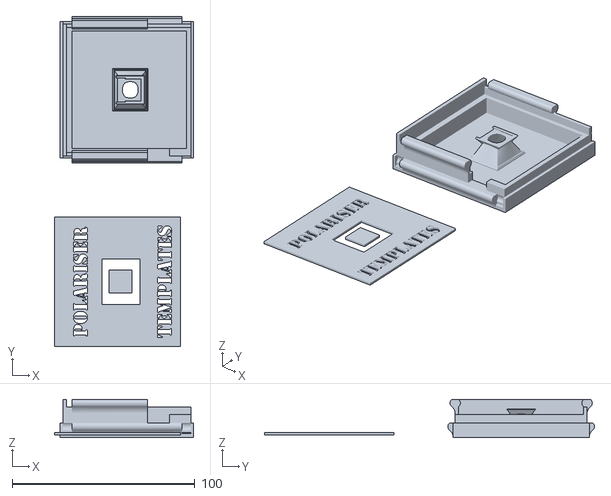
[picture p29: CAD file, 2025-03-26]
usermods/Enhanced Diffuser (Classic)/Enhanced Diffuser (Classic) Assembly.stl
76.2 x 180.6 x 20.9

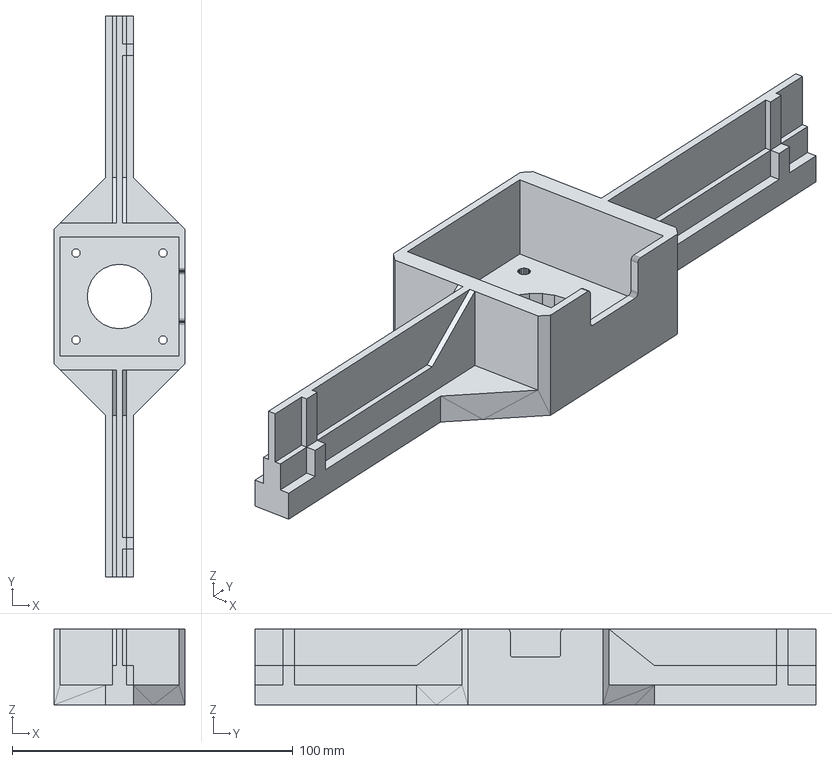
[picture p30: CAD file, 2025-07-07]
files/Classic/V1/Turntable_Base_smallNema.step
46.6 x 200.0 x 27.0 mm

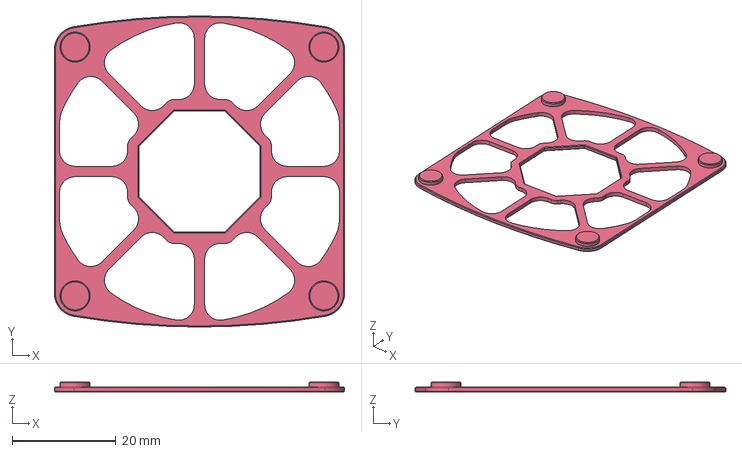
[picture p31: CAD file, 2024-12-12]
files/Imaging-Unit/STEP/5-Light_polarizer-cutout-paper.step
56.0 x 60.0 x 2.00 mm

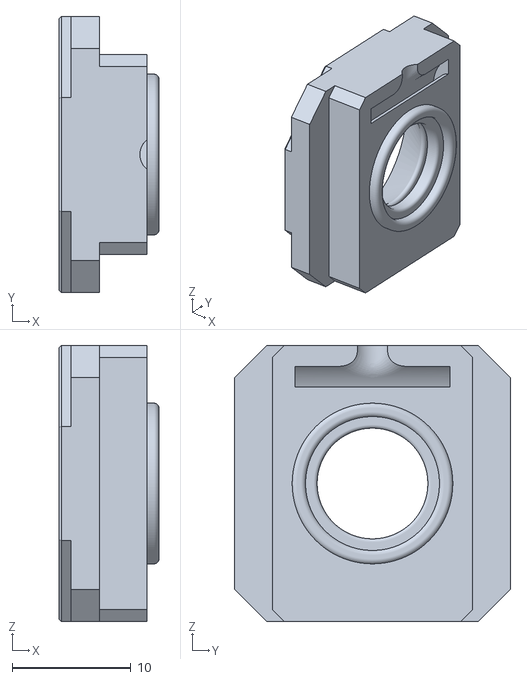
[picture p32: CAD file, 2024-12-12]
files/Imaging-Unit/STL/4-camera-polarizer-opaque (Meshed).stl
8.40 x 23.2 x 23.2

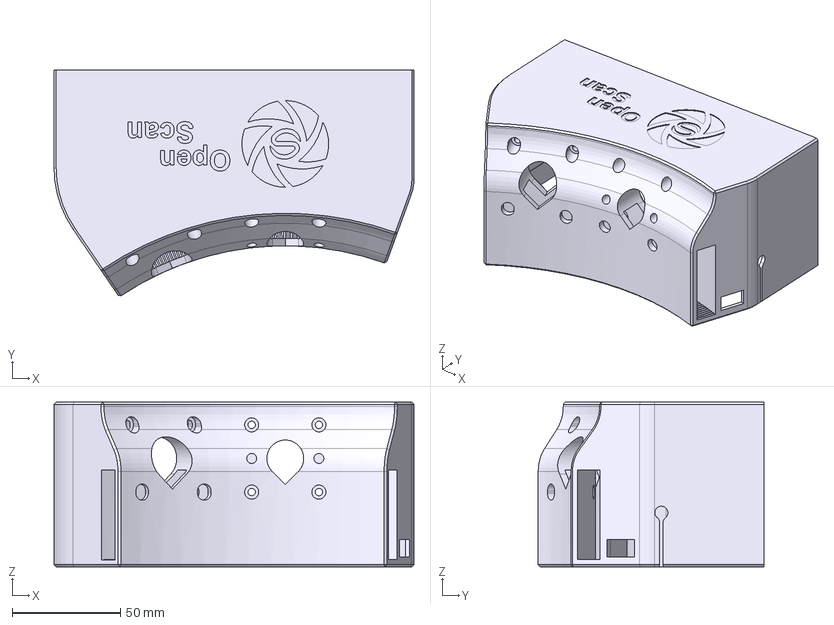
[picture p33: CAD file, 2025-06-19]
files/Midi/V2.4/STEP/1-base.step
166.0 x 104.1 x 76.0 mm

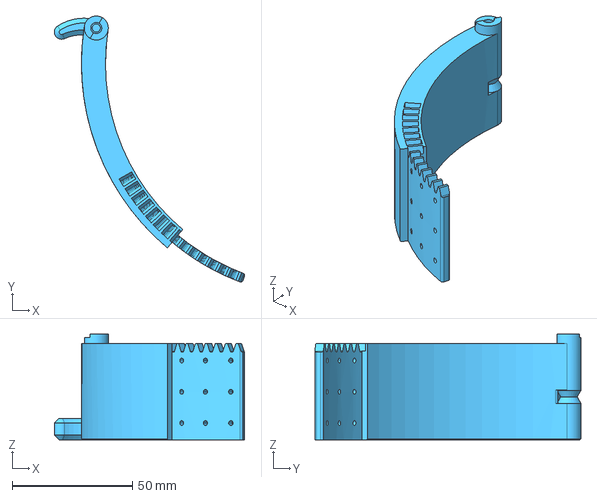
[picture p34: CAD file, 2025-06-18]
files/Mini/V2.4/STEP/2-rotor-segmented-in-three--part-1.step
79.2 x 110.6 x 44.0 mm

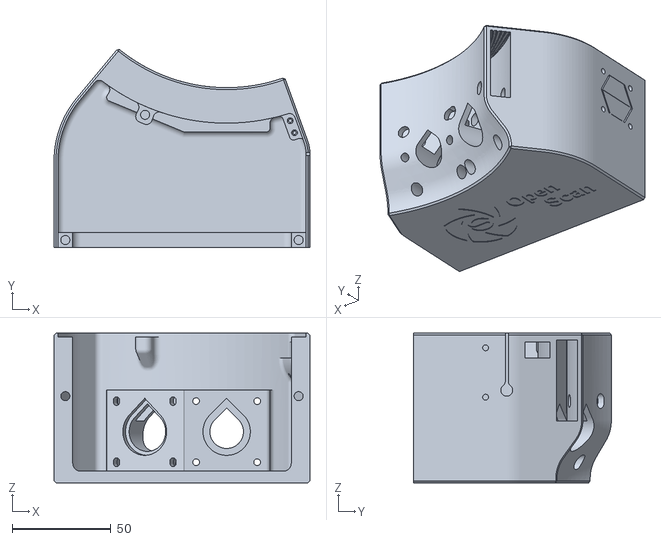
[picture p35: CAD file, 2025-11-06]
files/Mini/V2.4/STL/1-base (Meshed).stl
129.8 x 100.3 x 76.0

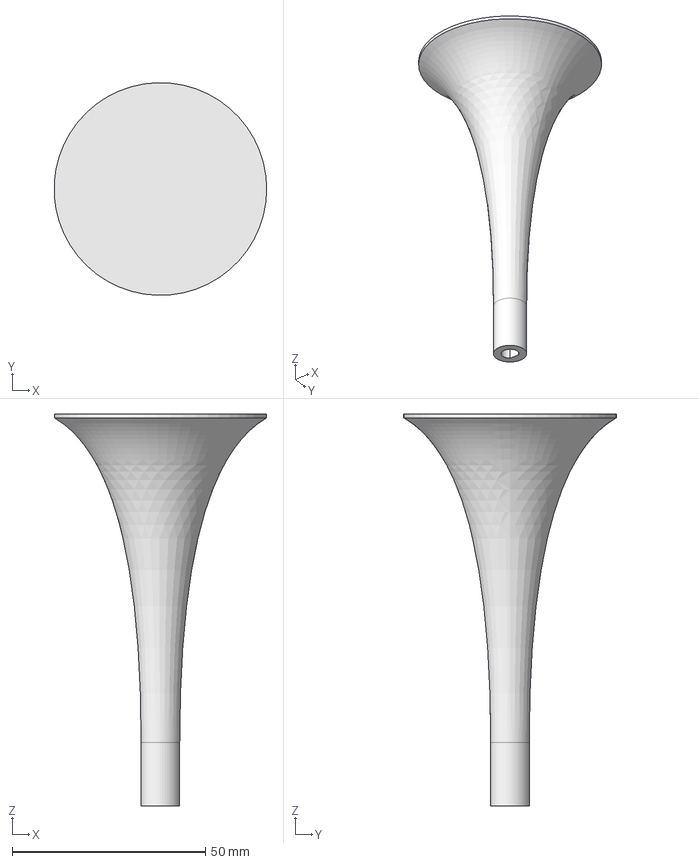
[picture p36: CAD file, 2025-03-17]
files/turntables/Midi/STEP/Turntable-110mm-object.step
54.9 x 55.0 x 101.4 mm

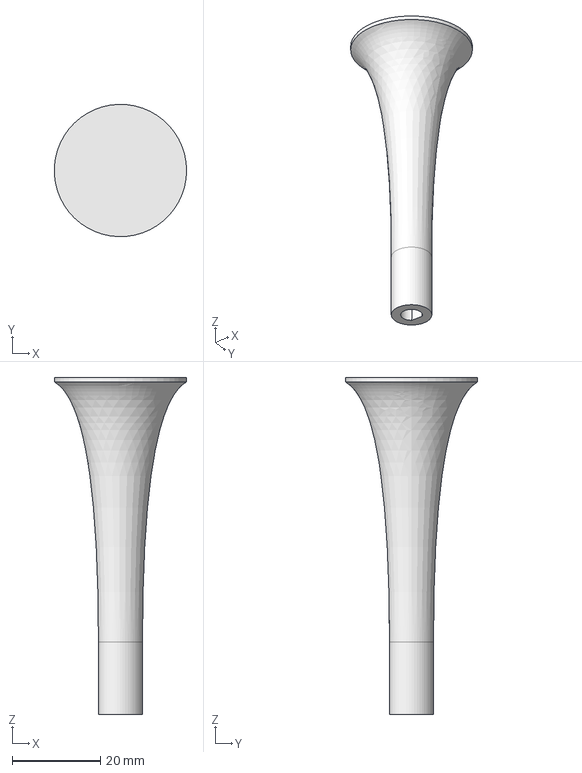
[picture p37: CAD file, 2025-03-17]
files/turntables/Mini_and_Classic/STEP/turntable-60mm-object.step
30.0 x 30.0 x 76.4 mm

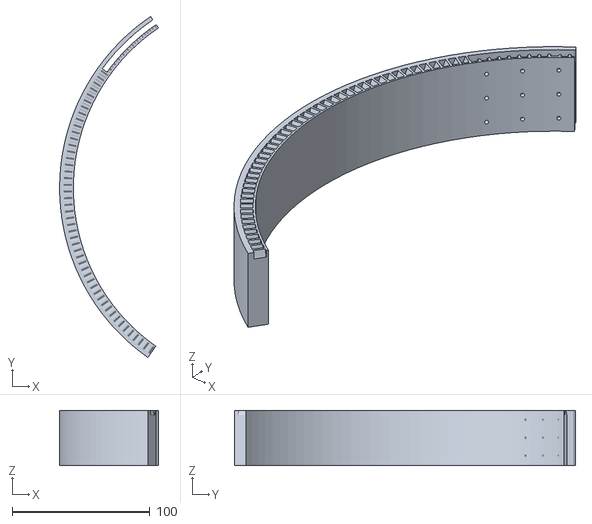
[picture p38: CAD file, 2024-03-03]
OS-Midi/2-rotor-segmented-in-two--part-2.stl
71.6 x 247.2 x 40.0

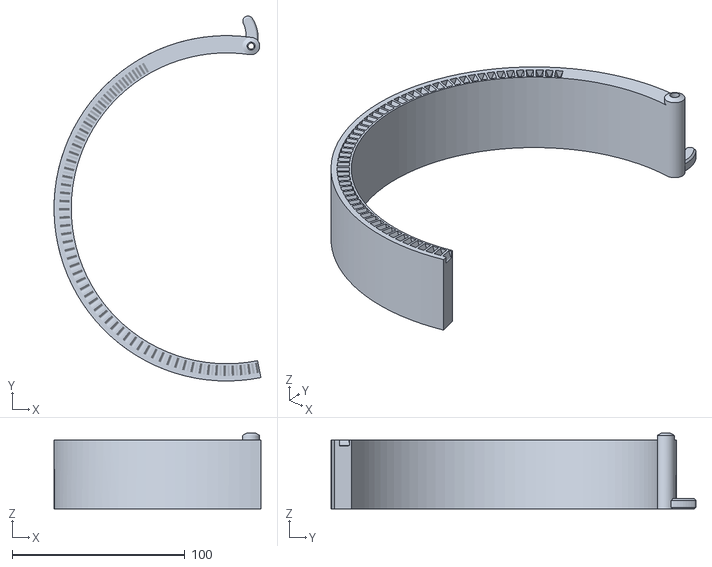
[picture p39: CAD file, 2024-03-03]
OS-Mini/V2/2-rotor-unibody.stl
119.8 x 211.4 x 44.0

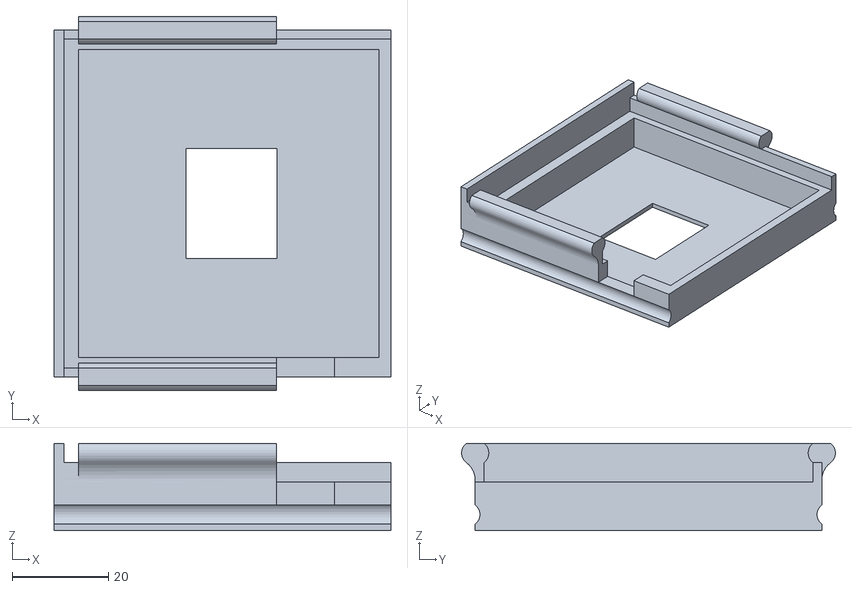
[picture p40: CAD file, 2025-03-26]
usermods/Enhanced Diffuser (Classic)/Enhanced Diffuser (Diffuser Only).stl
70.1 x 77.9 x 18.2

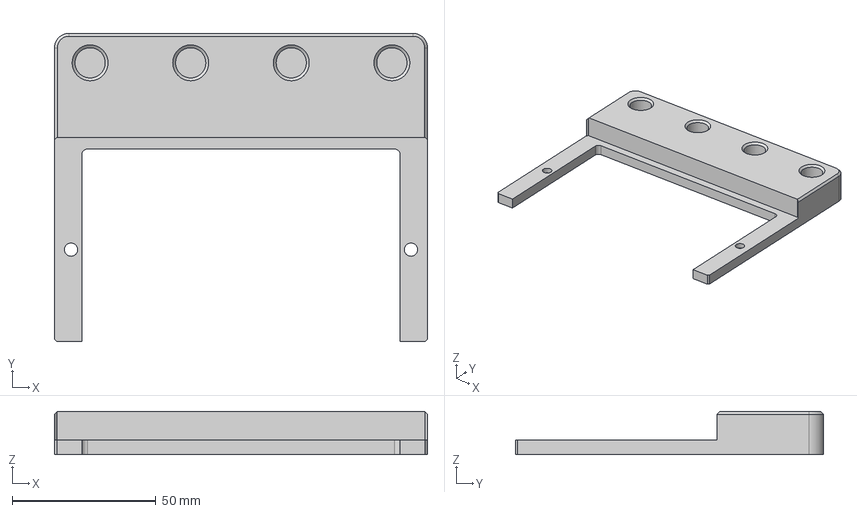
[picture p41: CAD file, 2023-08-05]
usermods/Platform Holder/Platform_Holder.step
129.8 x 107.2 x 15.0 mm

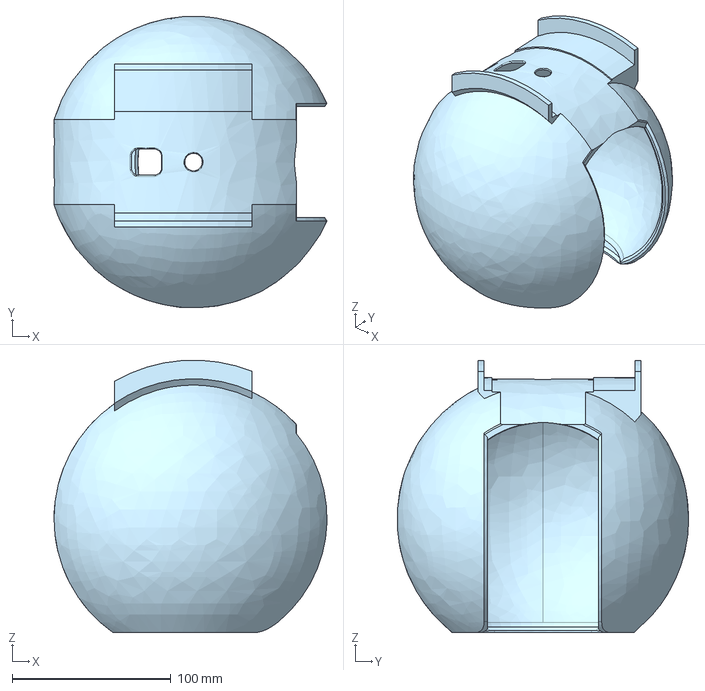
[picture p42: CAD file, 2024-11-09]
usermods/ScanDome/ScanDome v1.2.step
172.2 x 183.8 x 171.8 mm

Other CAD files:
files/Midi/V2.4/STL/1-base (Meshed).stl
usermods/Turntables for D-shaped Shafts/80mm Stand for 5cm objects.3mf
files/Classic/V1/Turntable_-_Adapter_small.step
files/Imaging-Unit/STEP/3-IU-frame.step
OS-Midi/spherical-dome.stl
OS-Mini/V2/optional-spherical-dome.stl
OS-Mini/V2/spherical-dome.stl
files/Classic/V1/Adapter1.step
files/Classic/V1/Adapter1.stl
files/Classic/V1/Adapter2_-_Gear_large.stl
files/Classic/V1/Control_module.step
files/Classic/V1/Control_module.stl
files/Classic/V1/Gear_-_Small_v1.step
files/Classic/V1/Gear_-_Small_v1.stl
files/Classic/V1/Gear_-_Small_v2.step
files/Classic/V1/Gear_-_Small_v2.stl
files/Classic/V1/Pi Shield_Base_Slider.stl
files/Classic/V1/Pi Shield_RPi_with_Ringlight_and_Network+USB.stl
files/Classic/V1/Pi Shield_RPi_without_Ringlight.stl
files/Classic/V1/Polarizer Classic_black.stl
files/Classic/V1/Polarizer Classic_black_presupported.stl
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

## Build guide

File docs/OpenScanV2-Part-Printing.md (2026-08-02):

# Part Printing Guide

The OpenScan devices come in different flavors. The Mini is the typical al-in-one version for smaller objects up to 8-9cm in diameter. The Midi is the larger sister when going for larger objects up to approx 15cm in diameter. The classic allows for easy use of DSLR and mirrorless cameras, which can increase the scan quality (at the expense of owning rather expensive additional equipment). The Mini and Midi come with support of the green shield (V1) and black shield (V2). The classic is currently missing a good looking integration of the black shield (only aesthetics). All parts are located in their corrspondingly named folder. Every part has a preceding number, e.g. "1-base.stl" to help you structure your printing and building process. Some parts come in different variants, e.g. the rotor as unibody part or segmented in two or three, all labeled with "3-..." as preceding number. This indicates that you only need *one* variant of this part. For a full set of parts, you have to print all parts of the corresponding folder for the corresponding model, i.e.

| Version | Needed Parts (incl. Links) |
| :---: | :---: |
| Mini V1 (still going strong) | [**Base Parts Mini V1**](../files/Mini/V1/) and [**Turntables**](../files/turntables/Mini_and_Classic/)|
| Mini V2.4 | [**Base Parts Mini V2.4**](../files/Mini/V2.4/) and [**Imaging Unit**](../files/Imaging-Unit/) and [**Turntables**](../files/turntables/Mini_and_Classic/)|
| Midi V2.4 | [**Base Parts Midi V2.4**](../files/Midi/V2.4/) and [**Imaging Unit**](../files/Imaging-Unit/) and [**Turntables**](../files/turntables/Midi/)|
| Classic V1 | [**Base Parts Classic V1**](../files/Classic/V1/) and [**Turntables**](../files/turntables/Mini_and_Classic/)|

Also, have a look at the [**Usermods**](../usermods/).

## Print settings and material
The device was designed with FDM printing in mind. The device should be sturdy since it has some heavy and moving parts attached and the electronics is also generating some heat. General print settings are:

- 3-4 walls
- 5-6 top and bottom layers
- 30-40% infill cuboid/gyroid/hex/grid is recommended
- **a layer height of 0.2mm is highly recommended** for proper functionality since all critical dimensions for tolerances and clearances are a multiple of 0.2mm.
- All parts are print-in-place with included support structures. Deactivate automated slicer supports.
- smooth or satin bed surface is recommended **Heavily structured print surfaces, such as powder-coated, will impact the dimensional accuracy of the rotor height.** This can cause additional friction or improper alignment.

The cogwheel/gear for the rotor motor might have an over- or undersized center hole, depending on your printer settings and capabilities. *It is recommended to print out this gear in three sizes, 95%, 100%, and 105%*, to ensure that one of the gears fits. The gear should fit snugly in the shaft with sufficient friction to hold it in place, but should not require excessive force to seat it. Alternatively, you can print out cogwheels/gears with varying (inner) hole/perimeter compensation in your slicer settings, which slightly expands or contracts holes of a model.

While it is okay to use PLA, PLA can slowly deform under the warmth and weight of the motors, when having multiple long scanning sessions in warm environments. Thus, it is recommended to use PETG or ABS/ASA (if your printer can reliably print those). Further, when using PLA, it is highly recommended to reduce the V_ref of the drivers to 0.5V to limit the heat generation.
As for color, a matte and dark color is recommended for all, but the translucent polarizer part. This simplifies the process of cutting out background in the images. The translucent polarizer part should be printed in a material that lets through light. Transparent PETG works good or "natural" colored PLA and ABS/ASA that contain very few pigments work great.
SLA resin is not recommended since many resins do not have the ductility or heat resistance (but users made it work).

## Built-in bridging help for V2 versions
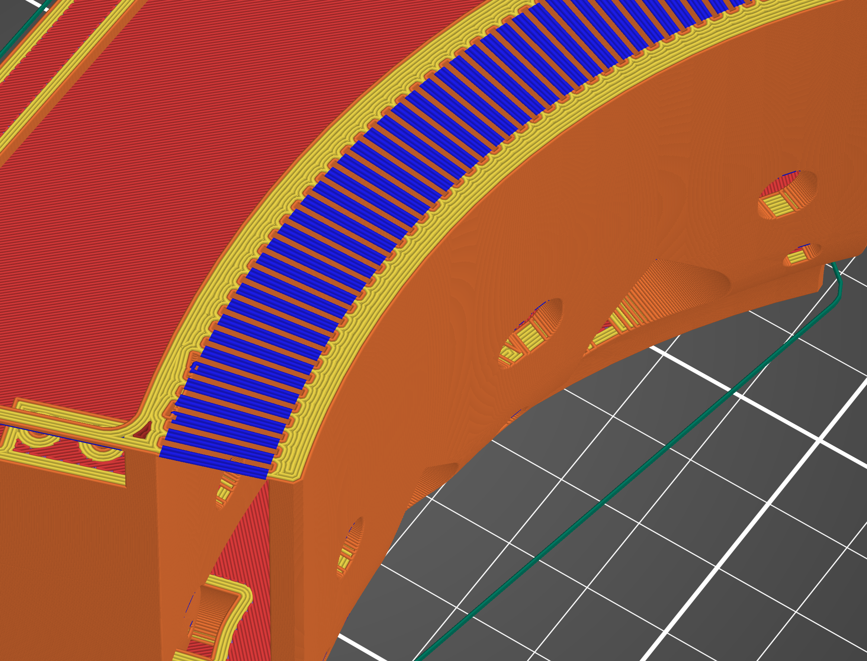
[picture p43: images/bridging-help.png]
Scanner

The **V2.X parts are designed as print-in-place**, i.e., no part re-orientation or supports are required. When supports are needed, then they are already modeled into the files.
The **V2.X's have included bridging helpers** so your printer always takes the shortest bridging path when printing the rotor housing. This remedies the issue with many slicers when printing long but narrow overhang bridges of curved surfaces. No more screwed up bridges because a slicer had a bad day. **You do not need additional, slicer generated supports for the V2 models**. 

## Finished Printing
When all parts are printed, go over to the [**Electronics Start-up guide**](/OpenScanV2-Electronics.md) and confirm that the electronics is working properly. You can then continue with the [**Assembly guide**](/OpenScanV2-Assembly.md).

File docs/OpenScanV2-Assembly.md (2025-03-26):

# Building Manual OpenScan Mini & Midi V2

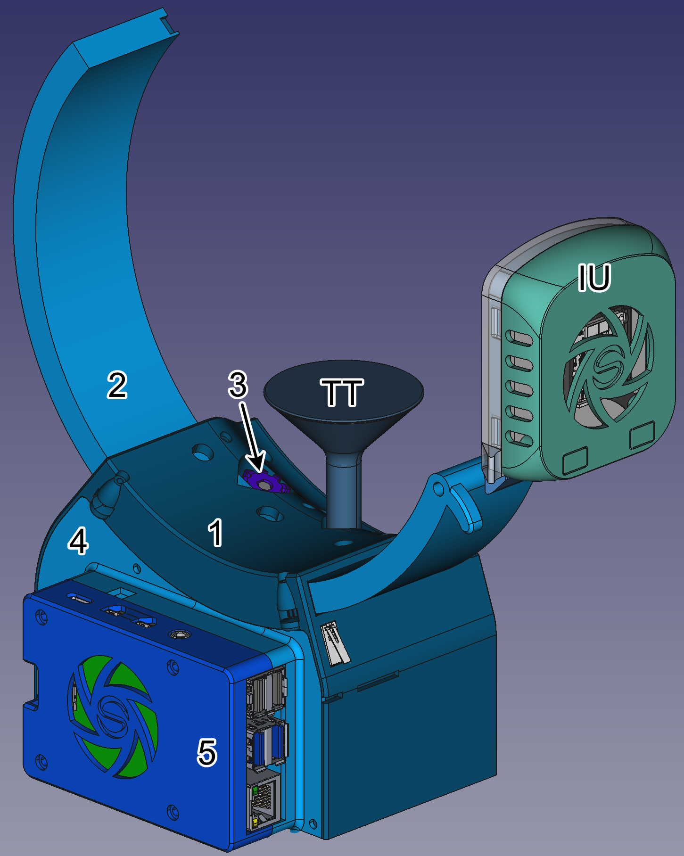
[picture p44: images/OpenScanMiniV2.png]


# Intro

Various parts and hardware were updated from V1 to V2 to improve rigidity and user-friendliness, especially in printing. No more part orientation and support structure settings in your slicer. Just print-in-place parts. The V2 design natively supports the V2 shields ("black shield"), which are currently inofficially available as a prototype on Discord.  

V2 also uses heat inserts M3x4x5 (thread size x length x outer diameter), widely popularized in 3D printing, especially in Voron-style printers. For them, a *soldering iron* with a spare (or sacrificial) tip or special heat insert tip is required. Make-shift solutions with M3 bolts and lighter are not recommended due to the serious risk of burning your fingers.
All other hardware parts, such as RPi and Arducam IMX519, have not changed from the V1.

**have a look at the [**Assembly Photo Guide**](../images/assembly/) under ../images/assembly/ ! A kind user shared an extensive collection of assembly photos**

# Printing and preparing the parts

All V2 parts are designed as print in place, i.e., no part re-orientation or supports are required. When supports are needed, then they are already modeled into the files. The recommended print settings are 4 perimeters and approx. 40% cubic infill. *Printing with 0.2mm layer height is highly recommended* because all dimensions and clearances of the parts are modeled as multiples of 0.2mm! Also, the rotor height is critical when you want to use the optional bearing upgrade. If you print the rotor on a powder-coated sheet, it will be slightly wider than anticipated. *Printing the rotor on a smooth or satin sheet is recommended*.
The parts should be printed in *PETG or ABS/ASA* if your printer can handle it. PLA can also work, but due to the enclosed design, excessive heat from the motors and drivers can slowly deform PLA in the long term. When printing PLA, the motor currents MUST be adjusted to a working minimum to prevent heat creep of PLA (approx. 0.5A).
The cogwheel/gear for the rotor motor might have an over- or undersized center hole, depending on your printer settings and capabilities. *It is recommended to print out this gear in three sizes, 95%, 100%, and 105%*, to ensure that one of the gears fits. The gear should fit snugly in the shaft with sufficient friction to hold it in place.

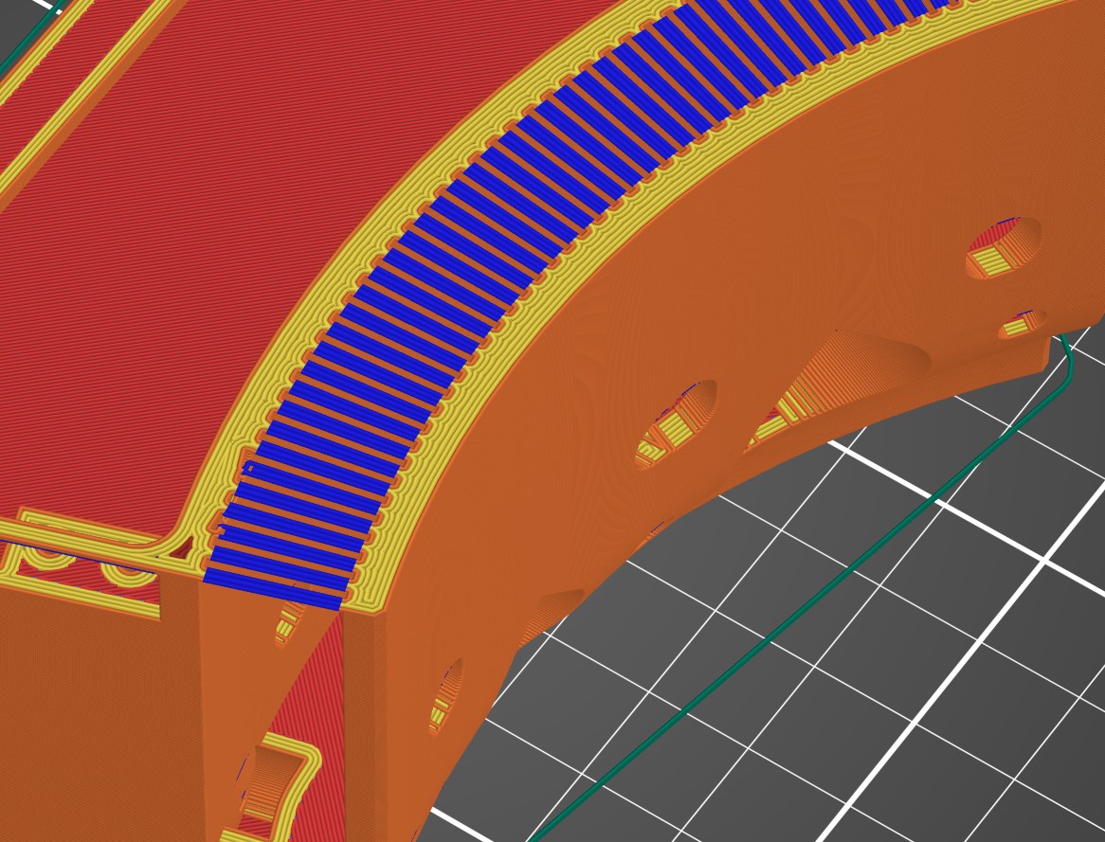
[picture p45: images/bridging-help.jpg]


Some parts have overhangs and bridges, and dangling filament parts should be cleaned. Take special notice of the base part since sacrificial bridges are modeled into it. Those intentional bridges are for helping your slicer slice and properly place bridges in the arced overhang for the rotor. The sacrificial bridges around the bearing insert points should be removed carefully to be able to insert bearings later on. Those bridges can be left untouched when not planning on using bearings at all.
As a last step, all required heat inserts should be appropriately set. Please take a look at the images below. Orange spots are mandatory heat inserts, and yellow spots are optional heat inserts for mods.

## Base

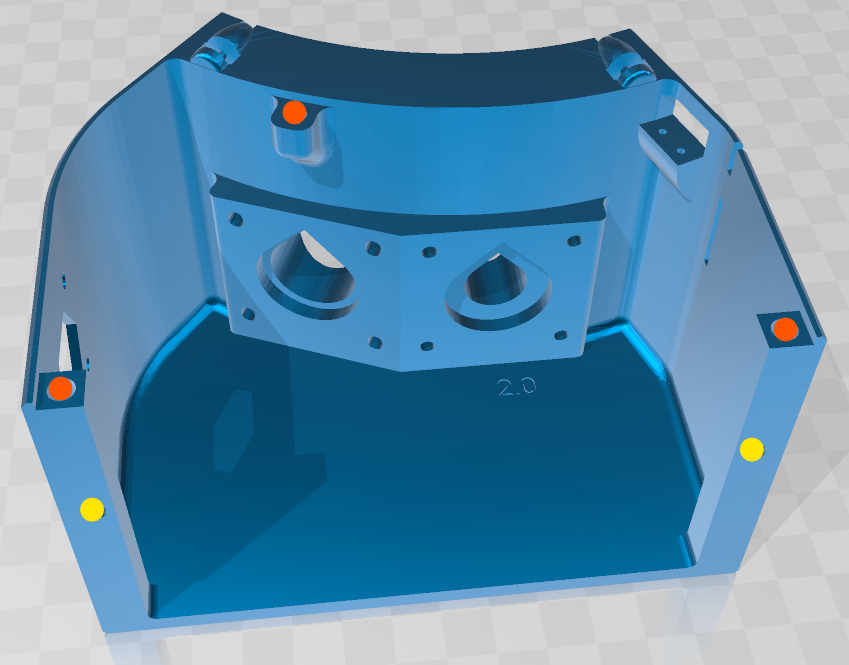
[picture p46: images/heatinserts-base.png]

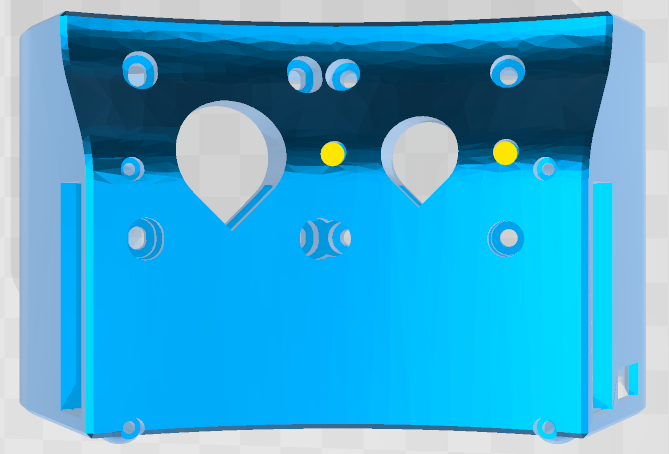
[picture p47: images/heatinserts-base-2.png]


Three inserts for the side cover are required. The additional ones at the bottom are for fixating the scanner to a table or optional turntable holder platform. The two optional ones on the top are for the light dome mod for more uniform illumination.

## Rotor

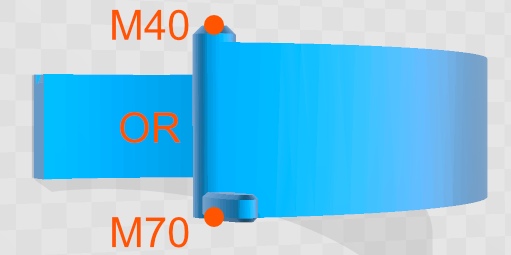
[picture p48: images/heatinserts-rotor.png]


*Only melt in ONE heat insert, depending on your available M3 bolt length!* M3x70 is recommended since it gives the most stability and secure fixation, but M3x70 is sometimes hard to source. If you have an M3x70, melt in the heat insert on the side with the little endstop nose. If you cannot source an M3x70 for a reasonable price (or low quantity), pick the longest M3 you can find. Instead, melt the heat insert into the conical side, labeled with M3x40.

## Imaging Unit Cover

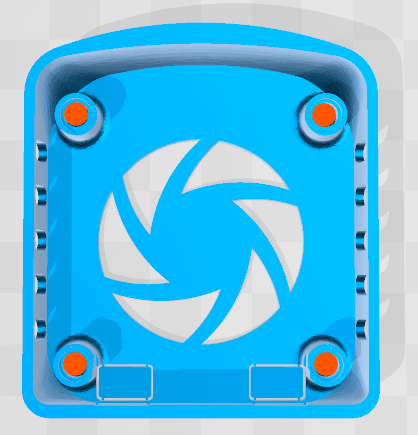
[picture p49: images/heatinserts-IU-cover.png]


Melt in four heat inserts as indicated. Try to leave the small ridges around the insertion point intact. They will help align the camera module later. There are some closed cut-outs. You have to remove the one that suits your JST-XH connector you solder onto (or you break away all cut-outs, you monster).

# Assembly

When all parts are printed and prepared, assembly is mainly straightforward. The STEP file I've shared here provides a 3D model of the whole assembly. Here is roughly a step-by-step assembly:

## Rotor

- (Segmented rotor) If you print the segmented rotor, the pieces should slide firmly into each other. If it does not slide well enough, take some fine sanding paper and sand the center fin a little, and try again. 

- (Segmented rotor) The nine holes of the segments should align. You can either guide 10mm filament pieces or 10mm M2 grub screws through the nine holes for locking the rotor parts into place. A little dab of CA glue permanently fixates them.

- (Unibody rotor) Nothing. The unibody rotor does not need further assembly.

## Base of Mini/Midi
- (Optional) Install tiny bearings with M2 screws for the rotor. They are located at the entrance and exit where the rotor is inserted. The flanges should point downwards. The tiny M2 screws screw directly into the plastic. Those screws are for straight alignment only, NOT for high clamping force, so do NOT overtighten them. 
- Install a Nema17 (preferably the 40Ncm) for the Rotor ([angled position](https://github.com/OpenScan-org/OpenScan-Design/blob/main/images/assembly/06_base_motor.JPG)). The slotted M3 holes are for proper gear meshing of the cog wheel and rotor later. Tighten the M3x8 screws only lightly at first. Add the best-fitting cog wheel/gear to the rotor Nema 17. The gear should have a reasonable friction and form fit. Check and align the motor before screwing them fully in. The cable connector might be challenging to reach if you orient them to the wrong side.

- For proper gear meshing, the height of the cog wheel on the Nema 17 shaft and the distance between the cog wheel and rotor must be adjusted. Insert the rotor into the base a little and set the position of the cogwheel on the shaft so that it aligns with the gear teeth of the rotor. Afterwards, loosen the M3 screws of the Nema 17, push the motor closer and tighten the screws again. Move the rotor forward and backward to check that the cog wheel is seated. You should be able to feel the friction of the stepper motor, 200 tiny "bumps" per rotation. 

- Optional: Installing the rotor endstop is done with either M1.6 regular or M2 self-tapping screws. Check the orientation of the end stop first so that the nose of the rotor surely hits the switch. Currently, the endstop only prevents the rotor from swooping against the base but does not use the endstop as a homing point (might change with a software update soon)

## Base Cover and Electronics Cover

- Place the shield in reverse, 2x20 connector points upwards, all remaining components downwards, onto the base cover and screw the M2.5 standoffs directly into the plastic of the cover. *They are not meant to bear large forces*. Do not overtighten them; otherwise, you strip the plastic. 

- (black shield) Insert the flat CSI camera cable into the RPi. Take care of the correct orientation since only one side has contacts. Guide the CSI cable through the slot of the black shield. Take care of proper orientation to prevent a kink in the cable.

- Place/press the RPi into the 2x20 connector carefully. The 2x20 connector has quite high friction, so take your time and do not accidentally bend the pins. Place the RPi cover on the RPi. You might have to angle it a little so that the cover does not collide with the I/O of the RPi.

- Use M2.5 screws to secure the cover to the RPI+shield assembly. Again, those should not be overtightened as they directly transfer  torque through the standoff into the plastic of the base cover.

- For now, do *not* screw the base and electronics cover to the base. We have to install some cables first, which is easier with an opened scanner. We build the Imaging Unit next.

# Imaging Unit

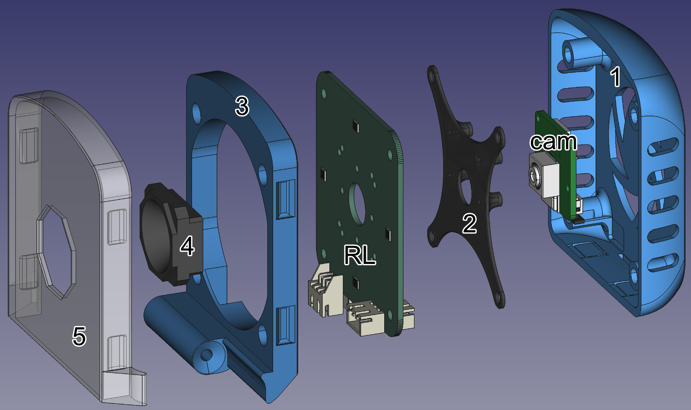
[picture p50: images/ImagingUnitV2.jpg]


- The imaging unit is a sandwich of parts, secured at the end with four M3 screws. Proper alignment before sandwiching them with screws makes the job quite easy. 

- The sandwich order from bottom to top is IU cover, camera mount (with camera), *ring light PCB*, IU frame,  camera polariser (opaque), and light polariser (translucent). Precisely like the numbering of the STL files (plus the ring light)

- Place the IU Cover in front of you. This will be the "base bread layer" of the sandwiched unit. Place the scanner base and cover next to it. You will need it soon.

- Use the screw-in OR slide-in (recommended) mount for the camera, and place and align the lens in the center of the mount. The Ardcam IMX519 has an offset of 0.4mm of its lens from the center line (Arducam's fault), which is corrected in the mounts and its screw holes. If the lens looks very offset-ish, you probably rotated the camera wrongly. If the slide-in mount feels too tight, scratch off some plastic with a screwdriver to widen the gap.

- Connect the cable to the camera. Take care of the proper orientation and *guide the cable through the slot in the scanner base first.* Then, take the IU cover and feed the flat CSI cable through the slotted hole. Again, check orientation. Lastly place the camera mount with camera onto the four screw holes. The small ridges close to the heat inserts of the IU cover should help with alignment.

- Check what JST-XH terminal, angled or straight, and ring light you have and which cut-out of the imaging unit cover you have to clear. Note, changing the terminal's orientation also changes its pinout order. Thus, the JST-XH connector pinout order has to flip, too.

- After deciding on the JST-XH terminal, carefully place the ring light PCB on the camera mount. The lens should also be in the center of the PCB. Afterwards, place the IU frame with already inserted M3 bolts onto the sandwich assembly and screw it down. The imaging part is now finished. 

## Polariser Unit

- In order to get the best quality pictures for photogrammetry, the images should not include reflections and bright spots. The simplest way to reduce reflections is to illuminate with linear polarised light, e.g. horizontally polarized, and then capture only cross-polarized light, i.e. vertically polarized light, with the camera. This is what the polarizer unit does. The opaque camera polarizer and translucent light polarizer sheet *must be aligned for cross-polarization*.

- Place a polarisation sheet in front of you and place the translucent polariser flat on top. Trace the outline with an exacto-knife, scalpel, or any sharp object. *Ideally, the orientation of the part should be parallel or perpendicular to the shape of the polariser sheet.* Cut the polariser sheet to size, including cutting out the camera hole, and glue the sheet on the outside of the translucent polariser. 

- Take the polariser sheet again and cut out a rectangular piece of 20x12mm (approx. 3/4"x 1/2") either  *parallel OR perpendicular to the outline of the already cut-out sheet* for the translucent polariser. Slide this piece into the slot of the opaque camera polariser.

- The octagonal opaque camera polariser fits into the translucent light polariser in multiple ways. *You have to press it in so that the two polarising sheets are oriented cross-polarized*. If you did not keep track of the orientation of the polarising sheets, look into a mirror in a bright room. Look through the camera polariser into the mirror and onto the light polariser. Now, slowly rotate the light polariser. It should slowly change brightness between grey and black. *When the polariser looks black, you find the cross-polarising orientation of the two polarisers.* Now press the camera polariser into the light polariser. A tiny droplet of CA glue might help to bond it together.

- Clip the polariser unit onto the IU. Done.

## Cabling, Electronics, and finishing the Build

The last step is connecting all wires and electronics to your OpenScan unit. Head over to the [electronics manual](../docs/OpenScanV2-Electronics.md) for pre-flight electronics checks. Then continue

- When you confirm that the electronics work and everything is adjusted, you can connect all the remaining wires and close the scanner.

# Modding your OpenScan
There are some user mods already available. My favorite is the illumination dome mod, which places a half-cylinder/half-sphere shell around the scanned area, minimizing auto-focus issues and smoothing illumination. You can freely share your mods on printables, Thingiverse, GitHub, or Discord. When sharing mods, ideally, you also provide print instructions, e.g., "print-in-place, N perimeters, M% infill, etc.".

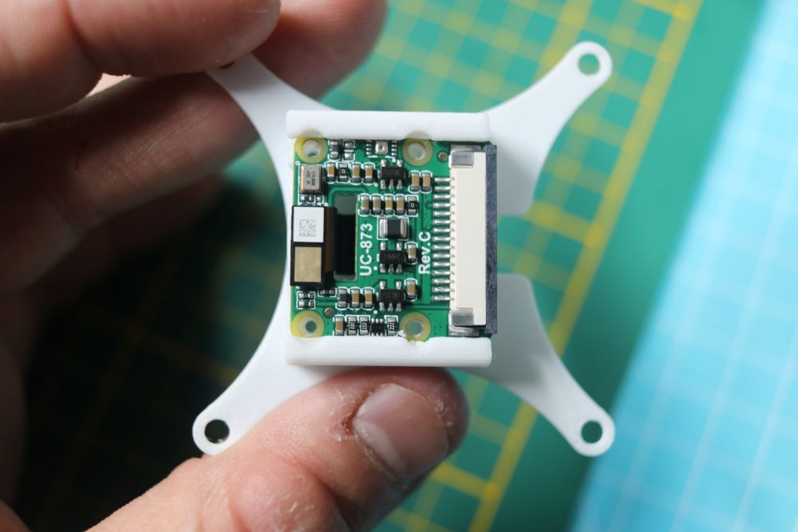
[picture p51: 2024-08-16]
images/assembly/20.0_arducam_slide-in.JPG

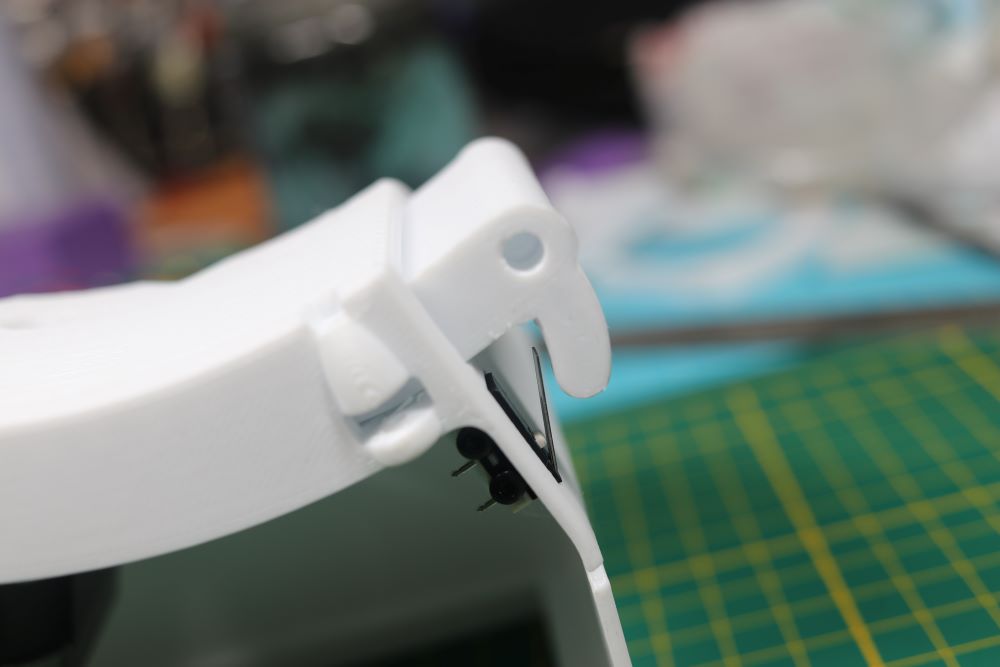
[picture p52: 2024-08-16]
images/assembly/05.1_endstop_open.JPG

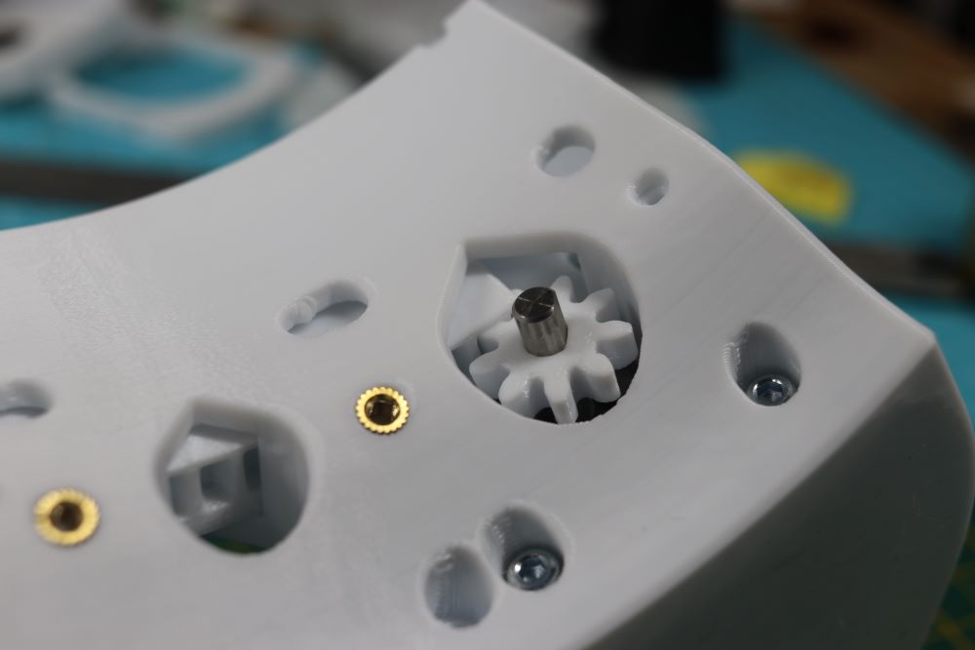
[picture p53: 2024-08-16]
images/assembly/07_motor_gear.JPG

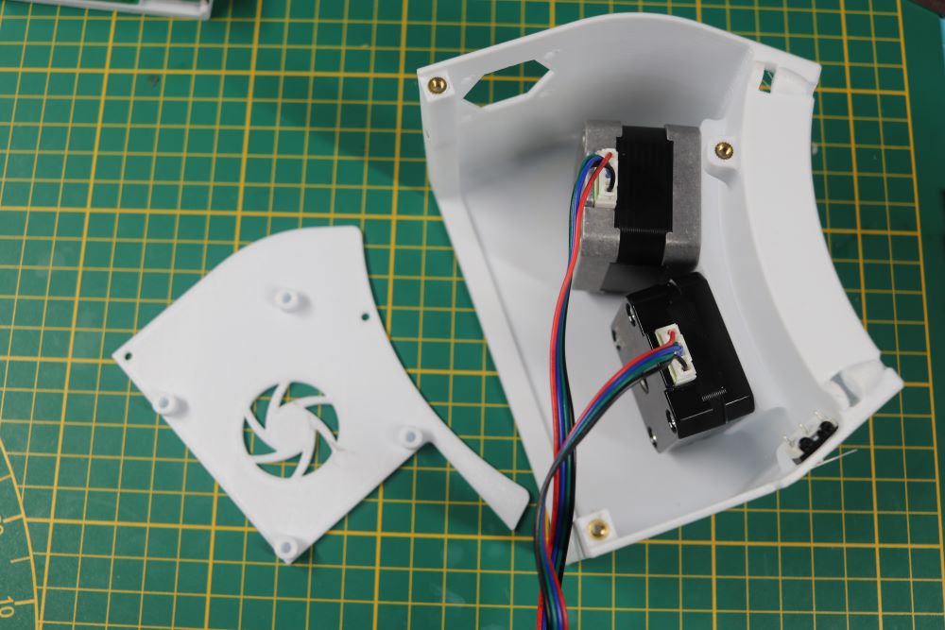
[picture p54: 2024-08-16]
images/assembly/08_motor_orientation.JPG

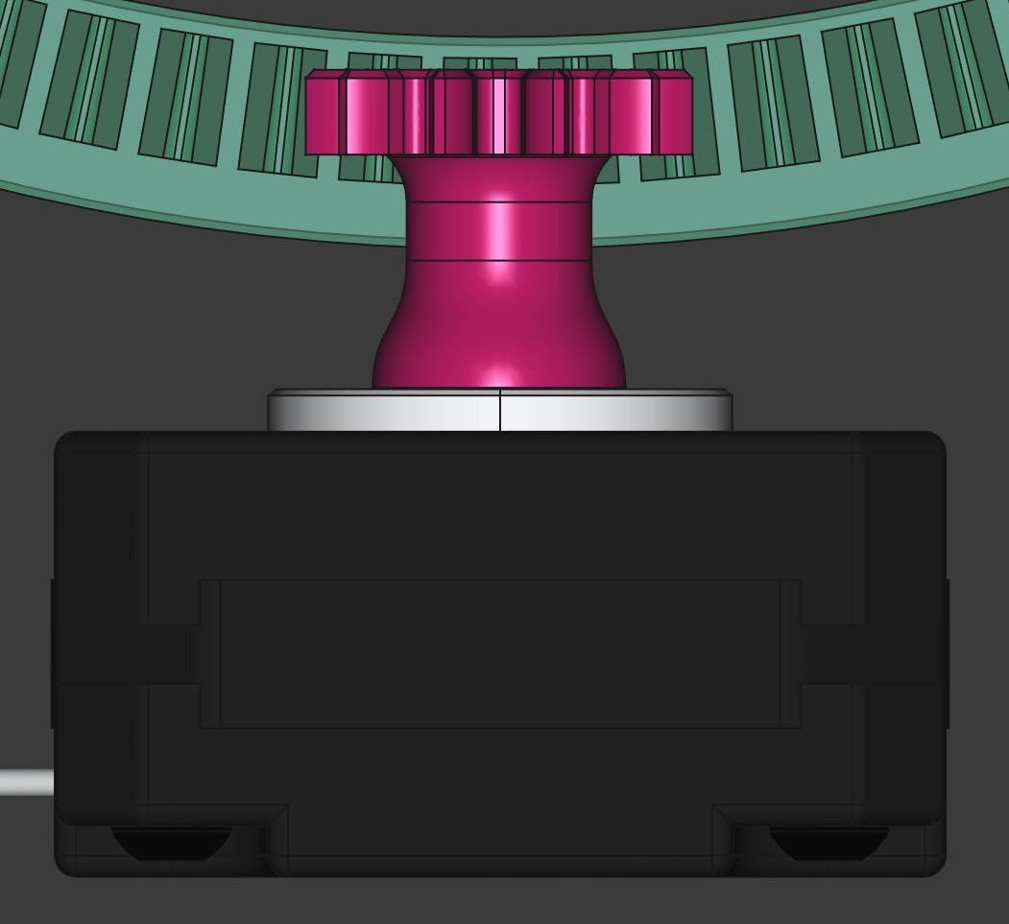
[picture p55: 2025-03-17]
images/assembly/07_motor_gear_new.jpg

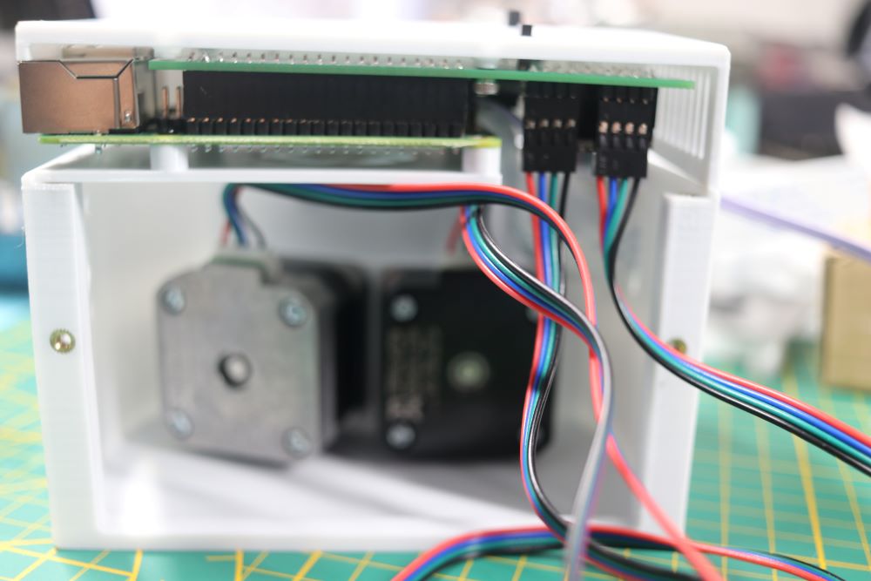
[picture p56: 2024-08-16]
images/assembly/15.0_IMG_5792.JPG

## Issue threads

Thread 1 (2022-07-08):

[Request] - Closed box containing the electronics, maybe even modular

OpenScanEu, 2022-07-08:
It might be a good idea to enclose the whole electronics into a box (including a fan mount ;)
This box could contain some quick-release mechanism so that it can be easily implemented into different scanner builds.

Unfortunately, my imagination is falling a bit short on this one...

probably-Erwins-Cat, 2023-03-06:
the first beta of an electronics enclosure was added into the v2 beta.

Closed 2023-08-05.

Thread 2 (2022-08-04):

Make STL files downloadable

tgoschuetz, 2022-08-04:
It's a mess to download the .stl files. There's no download for the full project, so you have to select them one by one, then download each one from the 3D view. Some don't even have a Download button, so you have to open the file in the browser and save it from there. Feels a little like being thrown back into the 80s.

Couldn't you just add a zip with all STL?

Thanks,
Tom

sokol07, 2022-08-09:
For now the decision is to keep the files as they are. This may change in future (when the repo will be expanded) but generally adding a .zip with all files to the repo isn't very likely (imo) - this would be an unnecessary complication for the versioning system.

However, you can download the whole repository using preferred git tool or by github page:
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

Closed 2022-08-15.

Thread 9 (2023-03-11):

I cant find the slide in mount

m1bcodes, 2023-03-11:
The instructions mention a slide-in mount for the ArduCam on the OpenScan Mini.
Unfortunately I was not able to find it anywhere.

OccasionalThingMaker, 2023-06-28:
Yeah. I was also unable. checked both the git repository and the files on printables. A bit of a shame that this hasn't been fixed, as the file obviously exists.

There's a community mod here. I used that. https://www.printables.com/model/502243-openscan-mini-arducam-ringlight-adapter

probably-Erwins-Cat, 2023-10-04:
I added a provisional slide-in mount for the V2 which should, in theory, also be compatible with the V1. Have a look at the V2 imaging unit parts.

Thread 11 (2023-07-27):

15cmx15cm 3D printer support

hadess, 2023-07-27:
I went through the v2 mini STL files, and it seems that the only thing that wouldn't fit on the bed of my Flashforge Adventurer 3 (15x15x15cm max) would be the rotor.

It would be great if this part could be printed as 2 separate parts to be joined when assembling.

(or maybe a way to buy just the rotor in the 3D printed parts on the shop? :)

probably-Erwins-Cat, 2023-07-29:
I honestly didn't think of smaller bed sizes than approx. 20x20cm for the Mini (and 30x30 for a potential Midi version).
I can have a look into splitting the rotor in smaller segments that can be reassembled. Nonetheless, a segmented rotor will not have the same dimensional accuracy and sturdiness as a single-segment rotor.

probably-Erwins-Cat, 2023-08-02:
Hey hadess,
I have designed a splitted rotor that would fit a 15x15cm build plate and will be fixated via CA glue and spare filament pieces as makeshift dowels. I will upload the rotor soonish(TM).

hadess, 2023-08-02:
Beautiful! I'll have to give it a spin soon, thanks for your work!

probably-Erwins-Cat, 2023-08-05:
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

Closed 2023-08-05.

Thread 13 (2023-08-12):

stl 100 times too big

sveggeth, 2023-08-12:
Pi Shield_RPi_with_Ringlight_and_Network+USB.stl
STL 100 x too large
need to scale down to print correctly.
Here is the resized file
[Pi Shield_RPi_with_Ringlight_and_Network+USB corrected scale.stl.zip](https://github.com/OpenScan-org/OpenScan-Design/files/12329613/Pi.Shield_RPi_with_Ringlight_and_Network%2BUSB.corrected.scale.stl.zip)

probably-Erwins-Cat, 2023-12-28:
all STLs are updated. The issue should be fixed.

Closed 2023-12-28.

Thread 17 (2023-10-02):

cog-Wheel to big[DESIGN]

HartmutA, 2023-10-02:
In my case the the cog-wheel for the OpenScan Mini V2 was to big

i increased the hole for the D-shaft radius 0.15 and printed it with a scale of 99%

Do you allow that your submitted design can be freely used, published and distributed as part of the OpenScan project? (If no, please specify the licence)
yes

If applicable, add screenshots to help explain. (Drag and drop)

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

HartmutA, 2023-10-02:
[99p_cog-wheel.stl.txt](https://github.com/OpenScan-org/OpenScan-Design/files/12781497/99p_cog-wheel.stl.txt)
Rename to .stl and print it with a scale 99%

probably-Erwins-Cat, 2023-10-04:
0.15mm is within the resolution of printing smaller holes of 3D printers. A small change in extrusion multiplier, retraction, water content of the filament, etc. and the inner hole can nominally change in size. This is, unfortunately, an issue that has to be solved by everyone individually and cannot really be solved nicely by sizing the hole larger. (This will result in other users running into too large holes and potential slipping)

Closed 2023-12-28.

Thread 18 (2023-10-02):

rpi-cover-v1 does not fit Pi3 (OpenScan Mini V2)

HartmutA, 2023-10-02:
In my case I had to change some things to fit with my Pi3

I changed following things:
1. I increased the mounting holes to 3.5mm
2. I increased the holes for the mounting screw head to 7mm
3.  I increased the distance for the PCB to 3 mm
4. I increased the hole for the HDMI connector
5. I modified the opening for the USB and RJ45 connector
6. I added 1mm more hight
7. I made a space sleeve 12mm for the distance between Pi and Shield

Do you allow that your submitted design can be freely used, published and distributed as part of the OpenScan project? (If no, please specify the licence)
Yes

If applicable, add screenshots to help explain. (Drag and drop)
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

[rpi-cover-v1.stl.txt](https://github.com/OpenScan-org/OpenScan-Design/files/12781685
[Distance.stl.txt](https://github.com/OpenScan-org/OpenScan-Design/files/12781699/Distance.stl.txt)
/rpi-cover-v1.stl.txt)

[rpi-cover-v1.stp.txt](https://github.com/OpenScan-org/OpenScan-Design/files/12781692/rpi-cover-v1.stp.txt)

probably-Erwins-Cat, 2023-10-04:
I will look into the backward compatibility of the shields for RPI 3b+. I realized that the RPI foundation changed the layout significantly from the 3b+ to 4 and (again) partially back again with the new RPI 5.
If you are fine, I would take your STLs (or STEP, in case you have them) and and them to the V2 STLs files as provisional versions until I find the time to adopt, re-measure and re-model the parts.

HartmutA, 2023-10-05:
Hi probably Erwin, i added the files in the previus post. I had to add a ".txt" and it looks a little bit mixed. but the links are ok.

probably-Erwins-Cat, 2023-12-28:
Hey HartmutA,
Unfortunately, there is a difference between the CAD models of various Raspberries and the physical one itself... Now, with the release of the RPI5, the same will repeat again. I modeled all parts after the CAD models, but they never fit the real-life part (same happens with Arducam).
I will update the RPI covers when I have all three relevant RPIs in my hand. I updated the covers provisionally, but I have the feeling that some others might now have fitting issues.

Closed 2023-12-28.

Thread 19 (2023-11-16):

Slide-in mout is missing.

Jan-Haas, 2023-11-16:
For the Mini Variante Arducam IMX519 16mp slide-in mount is missing by the 3D printing design.

probably-Erwins-Cat, 2023-12-28:
slide-in mount was added for the V2 version

Closed 2023-12-28.

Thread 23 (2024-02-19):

[BUG] An STL file for Classic has broken dimensions

FrenkK, 2024-02-19:
**Summary**

The file https://github.com/OpenScan-org/OpenScan-Design/blob/main/OS-Classic/V1/Pi%20Shield_RPi_with_Ringlight_and_Network%2BUSB.stl has a problem with dimensions, it is extremely large. I tried to convert from imperial, but it does not help.

**Screenshots/Video**

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

**What behavior did you expect? vs. what happened?**

I expected the part to have somewhat similar dimensions to the smaller shield.

**Steps to reproduce**

Try to import the part in Prusaslicer.

**Log files**

N/A

Aucklandadrian, 2024-02-20:
Same issue

I just printed a number of parts and this one comes out about 10-15% too big
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

probably-Erwins-Cat, 2024-02-29:
The PR that properly rescales the part was merged. The described issue should now be solved

Closed 2024-02-29.

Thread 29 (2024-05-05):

[DOKU] V2 rotor bearing model

jorgerobles, 2024-05-05:
On V2 readme, I notice bearing model is missing.

Checking https://es.aliexpress.com/item/1005005478195126.html and the .stp file not sure which should pick

Candidates are 602zz (7x2.8x3.5 bore 2mm) or MR72ZZ

Thanks in advance

probably-Erwins-Cat, 2024-06-26:
The BOM lists the bearing type, it is F692, e.g. F692ZZ

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

jorgerobles, 2024-06-26:
Thanks!

Closed 2024-06-26.

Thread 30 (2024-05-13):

[BUG]Wrong hole geometry on 5-electronics-cover--green-shield.stl for both Mini and Midi

FelixTheCrazy, 2024-05-13:
**Summary**

The holes for the Raspberry Pi are not aligned properly with the 5-electronics-cover--green-shield.stl for both the Mini and Midi.

**Screenshots/Video**

Please add a screenshot and/or video that demonstrate the malfunction.
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

**What behavior did you expect? vs. what happened?**

Them to line up?

**Steps to reproduce**

Print it and try and fit the Pi there.

Assume that the developers know nothing: share the steps to recreate the bug.

**Log files**

probably-Erwins-Cat, 2024-06-26:
I will check the part. According to the CAD model of the RPi etc. It should align and we corrected the alignement somewhat recently.

probably-Erwins-Cat, 2024-06-26:
should be solved now. I uploaded the wrong part last time.
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

Closed 2024-08-16.

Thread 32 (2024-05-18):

[DOKU] - Unclear which files to use

knicholes, 2024-05-18:
[edit] I've found https://github.com/OpenScan-org/OpenScan-Design/tree/main/Imaging-Unit, which is what I'm thinking is the most current?

[original]
When trying to print the pi cam v2 cover, it's unclear which cover to use.  There is no stl for the camera/mount in https://github.com/OpenScan-org/OpenScan-Design/tree/main/OS-Mini/V2

There ARE STLs in
https://github.com/OpenScan-org/OpenScan-Design/tree/main/OS-Mini/V2/legacy-deprecated/RC1
(NOT RC2)
https://github.com/OpenScan-org/OpenScan-Design/tree/main/OS-Mini/V2/legacy-deprecated/beta1
https://github.com/OpenScan-org/OpenScan-Design/tree/main/OS-Mini/V2/legacy-deprecated/beta2

The dates for all of these files are all "2 months," so it's not clear to me which is newer.  I can guess that either beta2 or RC1 are the newest by the numbering, but it'd be great to know which has been used and works before printing it out. The fact that beta2 and RC1 are under "legacy-deprecated" makes me think I'm looking in the wrong place, though.

probably-Erwins-Cat, 2024-06-26:
"deprecated" means those parts are not in use anymore and shouldn't be printed for new builds. They were replaced by up-to-date parts in the base folder /V2/. They deprecated parts are left in this folder for the early adopters of the Mini/Midi V2 so that they do not have to reprint all parts, just because they broke the IU and the newer IU has slightly different dimensions. Those folders will eventually be removed when the last early adopters re-printed the up-to-date parts.

The Imaging Unit (IU) is compatible with the Mini and Midi V2. Whenever I find time designing a Maxi version, I also guarante that the imaging unit will be compatible with that design. Thus, I placed the imaging unit in a separate folder.
Further, there might also be the option to design an alternative imaging unit, that holds your smartphone instead of a separate camera. As open-source project, we want to leave that modular design open for users.

In short, ignore the "deprecated" and "legacy" parts, they are for the early adopters, and jump directly to the new parts. The minimal building manual also has the same numbering scheme as the parts, e.g. **1**-IU-cover.stl which is the **1**st part in the building process of the IU.

probably-Erwins-Cat, 2024-08-16:
Updated the folder structure, so it is slightly less confusing

Closed 2024-08-16.

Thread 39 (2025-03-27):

[BUG] Imaging Unit frame does not fit on rotor

Bob-vdV, 2025-03-27:
**Summary**
The current version of the imaging unit frame STL [from here](https://github.com/OpenScan-org/OpenScan-Design/blob/main/files/Imaging-Unit/STL/3-IU-frame%20(Meshed).stl) does not fit on the rotor. The gap between the two holes is too small for the rotor to fit. The IU frame from the assembly instructions does not have one of the ends and just attaches to the side of the rotor. Could the IU file be reverted to this previous version?

**IU frame from assembly images**
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

**Latest IU frame**
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

Bob-vdV, 2025-03-28:
Just realized the 'slot' on the rotor is actually built in support, but it is very hard to remove and I had to cut it out. Could it be changed to something smaller, such as only the outer half of the cylinder? That would make it a bit more obvious it's support and also easier to remove, while it should still be enough to support the rest of the print.

probably-Erwins-Cat, 2025-03-30:
The same feedback was also provided from other users. The built-in support will be reworked to make it more fragile in a future update!

probably-Erwins-Cat, 2025-05-06:
should be fixed now. the built-in support is now clearly visible and easier to remove.

Closed 2025-05-06.

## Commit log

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2022-10-08 user mod D-shaped standoffs
    [55mm Stand for 10cm objects.3mf, 55mm Stand for 10cm objects.stl, 70mm Stand for 7cm objects.3mf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]
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2022-10-15 Create Parametric Object Mount Shaft for Openscan Mini v2.f3d
    [Parametric Object Mount Shaft for Openscan Mini v2.f3d]
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2023-03-05 initial beta release Mini v2
    [Base-beta.stl, Rotor-beta.stl, cam-rl-cover-beta.stl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]
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2023-03-06 uploaded the Classic STLs from thingiverse
    [Adapter1.stl, Adapter2_-_Gear_large.stl, Control_module.stl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]
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2023-07-28 update of V2 Mini to RC1 and including some mods
    [Platform Holder v3.stl, Platform_Holder.step, RPI-cover-for-V1-RC1.stl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]
2023-07-28 RC1 update, added provisional turntables
    [05a-Object holder - 3cm.stl, 05b-Object holder - 5cm.stl, 05c-Object holder - 7cm.stl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]
2023-08-02 updated camera parts, added camera mount, added splitted rotor design
    [cam-cover-RC1.stl, cam-holder-RC1.stl, cam-mount-RC1.stl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]
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2023-08-03 update Mini RC1 camera parts to be interchangable with Midi
    [07-polarizer_a_translucent.stl, 07-polarizer_b_black_support.stl, base-RC1.stl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]
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2023-08-05 Updated Mini V2, Added Midi (#12)
    * Update README.md
    * Update README.md
    * Added whole assembly as STEP file
    * Update README.md
    * update of V2 Mini to RC1 and including some mods
    * Update README.md
    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
    [55mm Stand for 10cm objects.3mf, 55mm Stand for 10cm objects.stl, 70mm Stand for 7cm objects.3mf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]
2023-08-12 separated the imaging unit from the Mini and Midi
    [IU-base.stl, IU-cam-mount.stl, IU-cover.stl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]
2023-08-14 updated imaging unit cover
    user Luddi measured the long term temperature of the imaging unit and we concluded that it might get too warm for PLA when scanning for a long time. also, added preliminary OS logo
    [IU-cover.stl]
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2023-08-28 updating the UI
    ... to fit the V1 ring light without sanding of the corners
    [IU-base.stl, IU-cover.stl, IU-polarizer-translucent.stl]
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2023-09-12 Updating Mini and Midi based on user feedback (#15)
    * RC1 update, added provisional turntables
    * Create README.MD
    * Update README.MD
    * updated camera parts, added camera mount, added splitted rotor design
    * update folder structure, introducing OS Midi RC
    * updated images, updated readme, added assembly of Mini V2
    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
    [01-Ring.stl, 02-Base.stl, 03-Backplate.stl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]
2023-09-22 Release of Mini and Midi V2
    practically updated all files and restructured folders.
    Mini and Midi bearing slightly updated, needs longer M2 now.
    IU now also has an offset-base, which makes it fully compatible to V1.
    [01-Ring.stl, 02-Base.stl, 03-Backplate.stl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]
2023-09-22 Release Version of Mini and Midi V2 (#16)
    * update Mini RC1 camera parts to be interchangable with Midi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
    [01-Ring.stl, 02-Base.stl, 03-Backplate.stl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]
2023-12-21 updated STLs
    now with separate covers for RPI3, 4 and 5 because they have slightly different layouts
    [RPI-cover-black-shield.stl, RPI-cover-green-shield.stl, RPI3-cover-black-shield.stl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]
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2024-02-20 Resolve BUG#23
    Resolves "[BUG] An STL file for Classic has broken dimensions OpenScan-org#23" - File had been saved with 114% scale setting. This file has the scale saved as 100% and is otherwise unchanged. I've checked the dimensions of the mounting points after this change and they appear to match the other variants of this part.
    [Pi Shield_RPi_with_Ringlight_and_Network+USB.stl]
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2024-03-03 Updated virtually all STLs for better resolution, updated manuals, updated assemblies, updated naming schemes
    [1-IU-cover.stl, 1-base.stl, 2-camera-mount--screw-in.stl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]
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2024-03-24 Updated rotor and IU to hex interface, assembly picters!!!, updated turntables for Midi etc
    [1-IU-cover.stl, 1-base.stl, 2-camera-mount--screw-in.stl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]
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2024-05-04 updated IU polarizer, green shield support, dome mod
    [4-base-cover--green-shield.stl, 4-camera-polariser-opaque.stl, 5-electronics-cover--green-shield.stl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]
2024-05-18 Adding ScanDome usermod for OpenScan Mini v1
    Contributed ScanDome usermod files for OpenScan Mini v1. The ScanDome can be printed to reduce background noise in images and to create a more uniform background for better extracting details from scanned objects.
    [ScanDome v1.1.step, ScanDome v1.1.stl]
2024-06-26 updated the electronics cover for the green shield
    thanks for user report that the holes do not align. I screwed up last time
    [5-electronics-cover--green-shield.stl]
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2024-07-18 updated rotor STLs so that IU is aligned towards center
    [2-rotor-segmented-in-three--part-1.stl, 2-rotor-segmented-in-three--part-2.stl, 2-rotor-segmented-in-three--part-3.stl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]
2024-08-16 whole restructuring of folders and documentation, rescaling of images for better view in browser
    [01-Ring.stl, 02-Base.stl, 03-Backplate.stl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]
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2024-11-18 Mini V2.1 parts updated
    because I was an idiot and added Midi parts to Mini directory...
    [2-rotor-segmented-in-three--part-1 (Meshed).stl, 2-rotor-segmented-in-three--part-2 (Meshed).stl, 2-rotor-segmented-in-three--part-3 (Meshed).stl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]
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2025-02-04 Add files via upload
    added files for polarizer, only works with Pi Shield_RPi_with_Ringlight_and_Network+USB.stl
    [Polarizer Classic_black.stl, Polarizer Classic_black_presupported.stl, Polarizer Classic_translucent.stl]
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2025-04-15 fixed holes in the models that caused import issues
    [1-base.step, 3-cog-wheel-10-teeth-0.15mm.stl, 3-cog-wheel-10-teeth-0.20mm.stl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]
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2025-06-15 Add files via upload
    Creating (mostly) clean step files for provided mesh files. FreeCad can do this with a small number of clicks. It refines away superfluous triangles that lie on the same plane. Doesn't do much for circles though.
    [Adapter1.step, Control_module.step, Gear_-_Small_v1.step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]
2025-06-18 V2.3 release
    including minor cosmetic finishes, updated BOM, paper dome mode
    [1-base (Meshed).stl, 1-base.step, 2-rotor-segmented-in-three--part-1 (Meshed).stl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]
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2025-11-06 Release of V2.4 CAD
    it is essentially the same as V2.3 except the CAD now has mounting holes for CSI cable extender
    [1-base (Meshed).stl, 1-base.step, 2-rotor-segmented-in-three--part-1 (Meshed).stl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]
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
